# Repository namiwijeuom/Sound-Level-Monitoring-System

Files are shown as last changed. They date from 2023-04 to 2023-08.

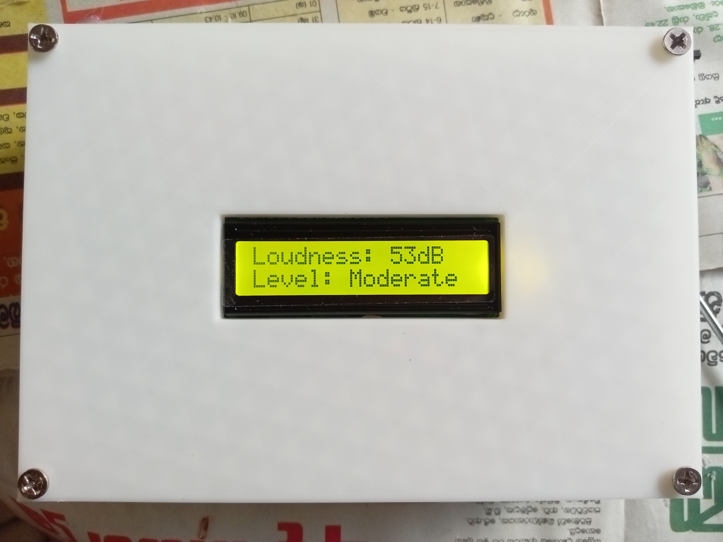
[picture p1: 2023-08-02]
Mid Evaluation Files/IMG_20230611_141432_171.jpg

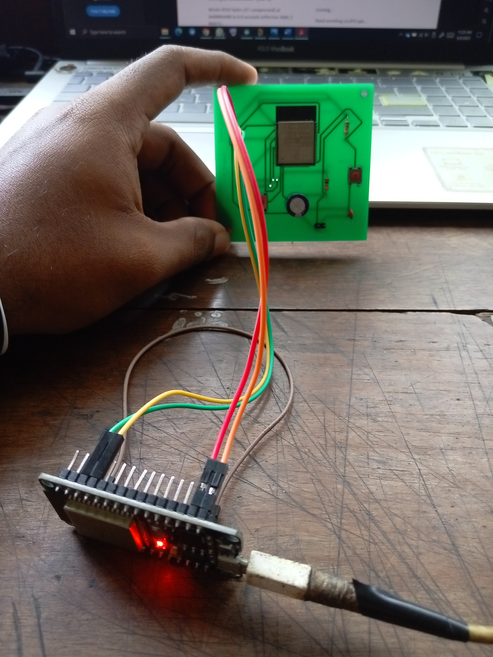
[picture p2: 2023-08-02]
Mid Evaluation Files/IMG_20230603_112545_107.jpg

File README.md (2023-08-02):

# Sound-Level-Monitoring-System
This is an individual project conducted under the module EN2160 - Engineering Design Realization, Semester 4, Department of Electronic and Telecommunication Engineering, University of Moratuwa, Sri Lanka.

Simulation Results- https://wokwi.com/projects/362552575811746817

Inside The First Prototype

It was not easy as before because all the designing and configuring tasks were to be done indicidually.

Before the Final Product

But it was an amazing experience to get on hands on experience on electronic product design and learned so many things at the end.

Final Product

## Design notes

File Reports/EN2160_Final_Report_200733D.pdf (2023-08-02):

1 | P a g e

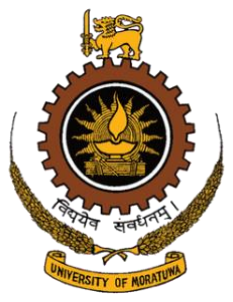
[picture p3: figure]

Department of Electronic and Telecommunication Engineering

University of M oratuwa

Final Report - Sound Level M onitoring System

Wijetunga W.L.N.K | - | 200733D

This report is submitted as a partial fulfillment of the module

EN2160 – Electronic Design Realization

24

th of July 2023

2 | P a g e

## Content

1. Introduction
2. Product Identification
3. Specifications of the Product
4. Extra Features That Are Included
5. Simulation
6. Conceptual Design
a. Conceptual designs for the product
i. Design - 1
ii. Design - 2
iii. Design - 3
b. Block diagrams drawn for the product
i. Block Diagram - 1
ii. Block Diagram - 2
iii. Block Diagram - 3
7. User Centred Design
a. Sketch
b. Block diagram
8. Evaluation Matrices
a. For the conceptual designs
b. Features added and removed in each design
c. For the block diagrams
d. Features added and removed in each block diagram
9. Selected Designs of the Product
a. Conceptual design
b. Block diagram
10. Implemented Designs of the Product
a. Schematic of the Implemented Design
b. Enclosure Design of the Implemented Design
c. PCB Design
11. First Prototype
12. Problems and Improvements of the Implemented Design
a. Problems/Improvements identified/proposed during the mid-evaluation

3 | P a g e
b. Problems/Improvements identified/proposed by users.
13. Improved Design
a. Schematic of the Improved Design
b. Enclosure Design of the Improved Design
c. PCB design and Gerber Files
14. The Product After Improvements
15. Any instructions for assembly
16. How to test for functionality
17. Bill of Materials
18. Appendix
19. References

4 | P a g e
1. Introduction
- Among the major types of pollution happening in the world such as water pollution and air pollution, sound pollution is getting a special attention in the society.
- Sound pollution is becoming a major concern in urban areas where there are high traffic conditions, in factories where there are large machines that generate noise and in work sites which involves using explosives a lot.
- With these promising issues, people tend to check the sound pollution level in their living area on a periodical manner and they tend to keep a track on past the sound pollution levels in the area currently.
2. Product Identification
- There are products already available in the market that can detect the sound level in a specific place.
- Examples of such devices can be found using the following links.
- https://www.amazon.com/noise-detector/s?k=noise+detector
- https://www.aliexpress.com/w/wholesale-automotive-noise-detector.html
- https://www.renkeer.com/noise-detectors-for-industrial-pollution/ ‘
- But they cannot keep a record either on the location or the past data.
- Considering the above-mentioned factors, it was decided to build a sound level monitoring device that can monitor and display the sound quality and level in a specific location and the data is directly stored in a database for further analysis.
- The device will be an IoT device as well.
- The level of sound will be displayed on a screen so the user can see the amount of sound pollution in decibels.
- It will further indicate whether the sound pollution level is low, intermediate, or high.
- It will be a portable device which can carried easily so the user does not need any extra space to pack the device.
3. Specifications of the Product
- The primary and foremost objective of this device revolves around its paramount capability to measure the prevailing sound level accurately and precisely within a designated area. Subsequently, this crucial acoustic data is meticulously stored in an extensive and comprehensive database, paving the way for exhaustive and in-depth analysis in the subsequent stages.
- Utilizing cutting-edge technology, the device employs a sound sensor to diligently gauge the acoustic intensity, precisely quantifying it in decibels (dB). This valuable information is then seamlessly portrayed on a highly convenient LCD display, thereby facilitating a comprehensive understanding of the prevailing sound pollution level in the environment.
- Users of this ingeniously designed device are presented with the invaluable privilege of effortlessly perceiving the sound level through the highly user-friendly display. Furthermore, they are granted unhindered access to an easily accessible ON/OFF switch, thereby empowering them with absolute control overpowering the device as they see fit.

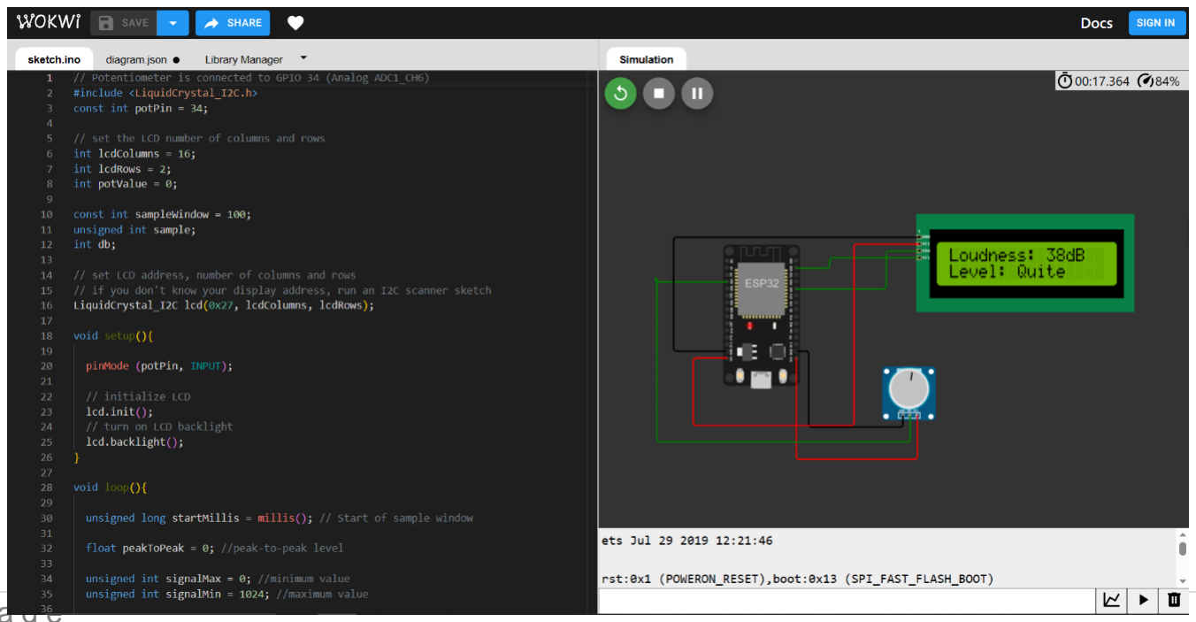
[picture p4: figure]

5 | P a g e
- To ensure optimal functionality, the device warrants a steadfast 5V power supply to effectively power up its intricate modules. Nevertheless, users are afforded the liberty to swap out drained batteries with utmost ease, thus ensuring a continuous and seamless operation of the device without any interruptions.
4. Extra Features That Are Included
- Along with the sound pollution level in dB being displayed in the LCD display, it will also be pushing the readings to an IoT platform, and a graph will be plotted over time to see the sound level in that specific location.
- It will indicate whether the sound level in the area is quiet, medium, high, or high risk in the display.
- As the IoT platform, Blynk IoT platform will be used, and it is accessible to anyone around the world.
5. Simulation
- Before implementing the solution, the functionality of the circuit proposed for the product was simulated and verified.
- The platform used was Wokwi online simulator.
- Wokwi Arduino simulator is a great online tool for simulating projects that use a development board. The app supports various popular development boards and MCUs such as the Arduino UNO, the Raspberry Pi Pico, the ESP32, and the ATTiny85.
- Therefore, during the simulation instead of using the ESP32-WROOM32D microcontroller, ESP32 Development board was used because the microcontroller alone was not available in the simulation platform.
- During the simulation, the microphone module that was proposed to be used for the product was not available.
- A microphone module captures sound in the environment and outputs a voltage signal which is proportional to the sound level.
- Therefore, the functionality of the microphone module was simulated using a potentiometer.
- The Wi-Fi connection and the things associated with Blynk application was not simulated and they were tested during the breadboard implementation of the proposed circuit.

Figure 1

6 | P a g e
- Link for the simulation - EDR_Sound_Level_Detection_System_V2 - Wokwi ESP32, STM32, Arduino Simulator (https://wokwi.com/projects/362552575811746817)
- Sketch used during the simulation is as follows.

// Potentiometer is connected to GPIO 34 (Analog ADC1_CH6) #include <LiquidCrystal_I2C.h>
const int potPin = 34;

// set the LCD number of columns and rows int lcdColumns = 16;
int lcdRows = 2;
int potValue = 0;

const int sampleWindow = 100; unsigned int sample;
int db;

// set LCD address, number of columns and rows
// if you don't know your display address, run an I2C scanner sketch LiquidCrystal_I2C lcd(0x27, lcdColumns, lcdRows);

void setup(){

pinMode (potPin, INPUT);

// initialize LCD
lcd.init();
// turn on LCD backlight
lcd.backlight();
}

void loop(){

unsigned long startMillis = millis(); // Start of sample window

float peakToPeak = 0; //peak-to-peak level

unsigned int signalMax = 0; //minimum value unsigned int signalMin = 1024; //maximum value

// collect data for 50 mS
while (millis() - startMillis < sampleWindow)
{

sample = analogRead(potPin); //get reading from microphone

if (sample < 1024) // toss out spurious readings
{
if (sample > signalMax)
{

7 | P a g e

signalMax = sample; // save just the max levels }
else if (sample < signalMin)
{
signalMin = sample; // save just the min levels }
}
}

peakToPeak = signalMax - signalMin; // max - min = peak-peak amplitude

Serial.println(peakToPeak);

db = map(peakToPeak, 50, 4000, 49.5, 90); //calibrate for deciBels

lcd.setCursor(0, 0);
lcd.print("Loudness: ");
lcd.print(db);
lcd.print("dB");

if (db <= 40)
{
lcd.setCursor(0, 1);
lcd.print("Level: Quite"); }
else if (db > 40 && db < 55)
{
lcd.setCursor(0, 1);
lcd.print("Level: Moderate"); }
else if (db >= 55)
{
lcd.setCursor(0, 1);
lcd.print("Level: High");
}
delay(600);
lcd.clear();
}

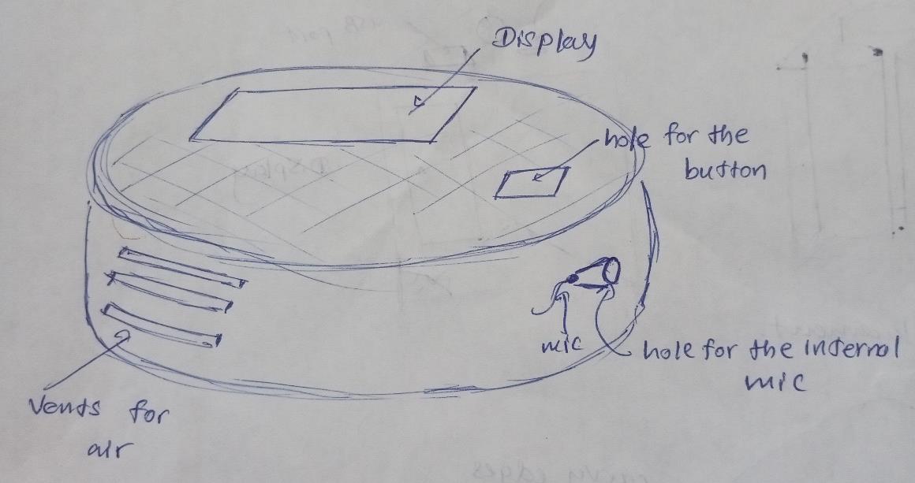
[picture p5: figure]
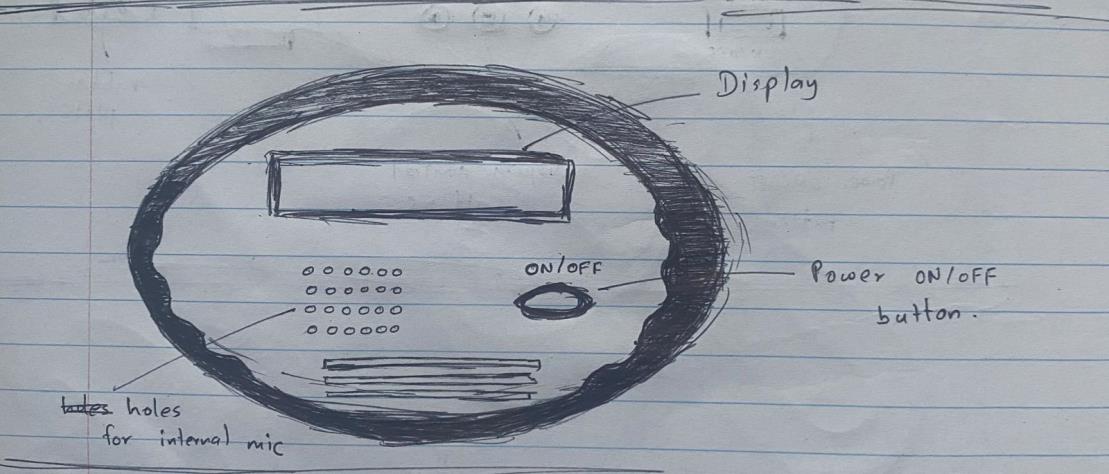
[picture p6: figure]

8 | P a g e
6. Conceptual Designs of the Product
- In the conceptual design cycle of designing concepts and making prototypes, different circuits, enclosures, and functional parts (If available) are considered by brainstorming ideas among the members of the design team.
- Then those ideas are combined to make a complete solution to the problem which is addressed.
- The underlying ideas are then grouped and using hand sketches those ideas are presented to get the optimal solution.
- Conceptual Designs Drawn
- After having many brainstorming sessions, the following conceptual designs were developed for the sound level monitoring system.
a) Design - 1 (Inspired from Amazon ALEXA)
b) Design - 2 (Handheld type design)

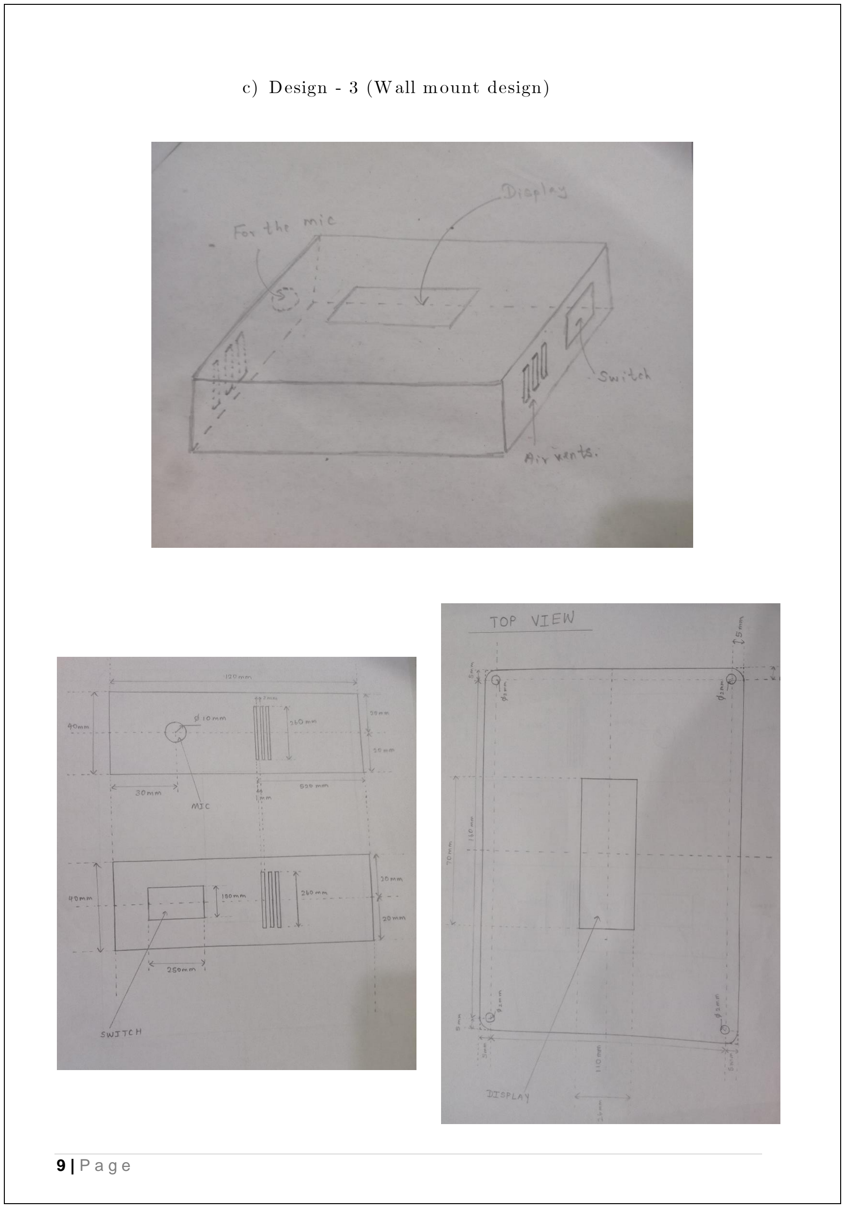
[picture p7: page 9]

9 | P a g e
c) Design - 3 (Wall mount design)

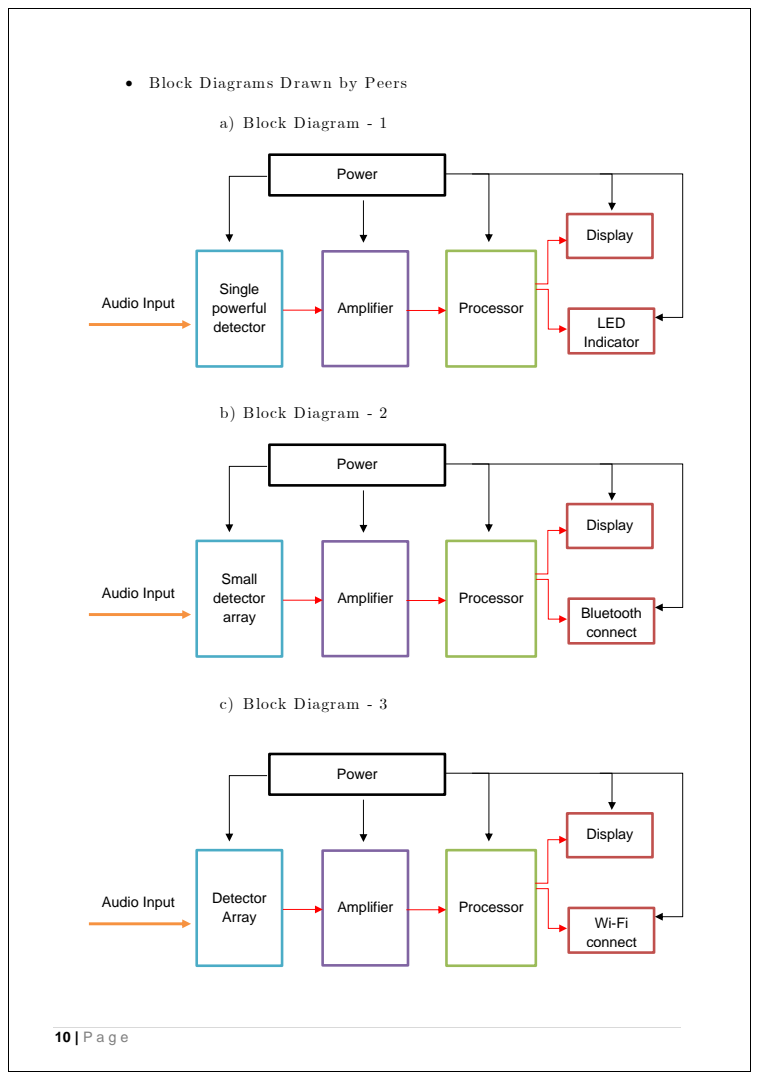
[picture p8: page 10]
a) Block Diagram - 1; b) Block Diagram - 2; c) Block Diagram - 3; Single powerful detector; Amplifier; Processor; Display; LED Indicator; Power; Audio Input; Small detector array; Bluetooth connect; Detector; Array; Wi-Fi connect

• Block Diagrams Drawn by Peers

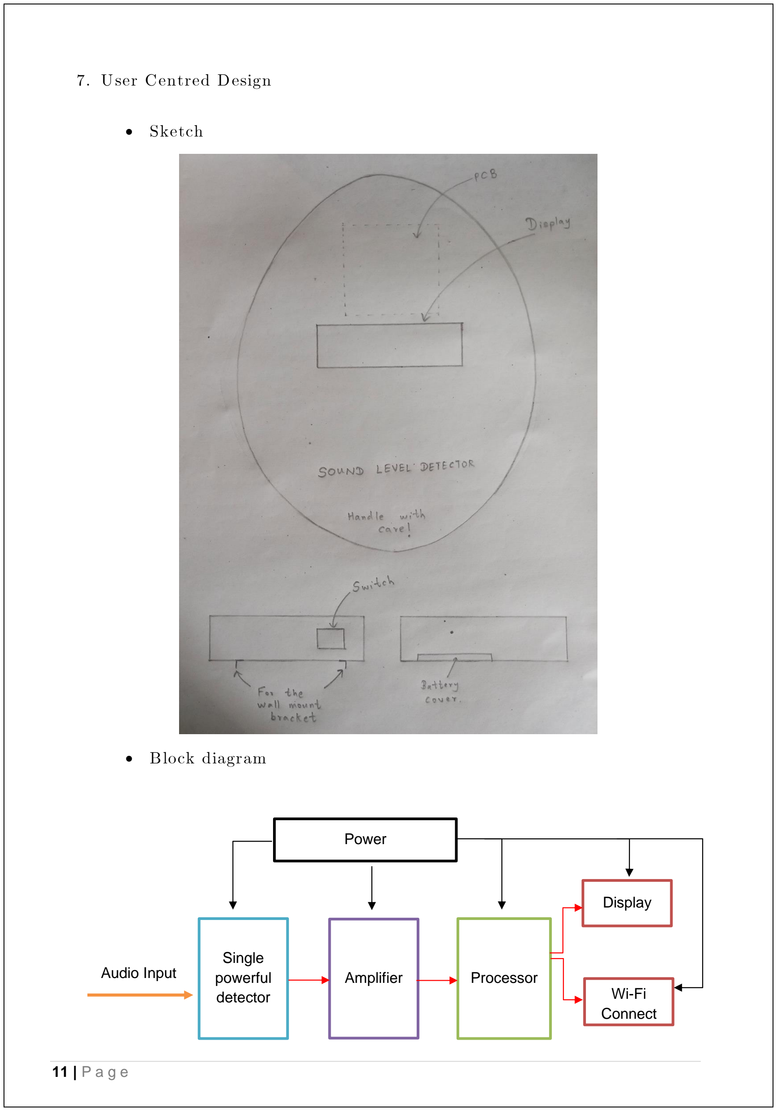
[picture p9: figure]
7. User Centred Design; • Sketch; • Block diagram; Single powerful detector; Amplifier; Processor; Display; Wi-Fi Connect; Power; Audio Input

12 | P a g e
8. Evaluation M atrices
- For the conceptual designs
- Features added and removed in each design
No. | Criterion | Design - 1 (Inspired from Amazon ALEXA) | Design - 2 (Handheld Type Design) | Design - 3 (Wall Mount Type Design) | Design - 4 (User Centred Design)
1 | Portability | 0 | 10 | 0 | 0
2 | Simplicity | 9 | 4 | 8 | 7
3 | Repairability | 8 | 8 | 8 | 8
4 | Manufacturability | 7 | 7 | 7 | 7
5 | Indoor use | 10 | 8 | 10 | 10
6 | Outdoor use | 0 | 4 | 9 | 0
7 | User friendliness | 5 | 3 | 8 | 6
8 | Aesthetic view | 5 | 4 | 3 | 5
9 | Competitiveness with existing products | 6 | 3 | 8 | 8
10 | Eco friendliness | 6 | 6 | 6 | 6
| Total M arks | 56 | 57 | 69 | 57
Criterion | Design - 1 (Inspired from Amazon ALEXA) | Design - 2 (Handheld Type Design) | Design - 3 (Wall Mount Type Design) | Design - 4 (User Centred Design)
Added features | • Indoor use • Simplicity | • Portability • Indoor use | • Both indoor and outdoor use | • Indoor use • Competitiveness with existing products
Removed features | • Outdoor use | • Simplicity | • Portability | • Portability • Outdoor use

13 | P a g e
- For the block diagrams
- Features added and removed in each block diagram
No. | Criterion | Block Diagram - 1 | Block Diagram - 2 | Block Diagram - 3 | Block Diagram - 4 (User Centred Design)
1 | Battery life | 8 | 6 | 6 | 6
2 | Simplicity | 6 | 6 | 5 | 5
3 | Repairability | 5 | 5 | 5 | 5
4 | Manufacturability | 6 | 6 | 6 | 6
5 | Indoor/Outdoor use | 5 | 3 | 5 | 5
6 | User friendliness | 4 | 7 | 8 | 6
7 | Response time | 6 | 7 | 7 | 7
8 | Reliability | 4 | 6 | 8 | 8
9 | Accuracy | 5 | 6 | 6 | 5
10 | Range | 4 | 8 | 7 | 6
| Total M arks | 53 | 60 | 63 | 59
Criterion | Block Diagram - 1 | Block Diagram - 2 | Block Diagram - 3 | Block Diagram - 4 (User Centred Design)
Added features | • Only one powerful detector to detect sound | • A detection array instead of a single detector for sound detection | • A detection array instead of a single detector for sound detection | • A detection array instead of a single detector for sound detection
Removed features | • No Wi-Fi or Bluetooth connection can be enabled. | • No Wi-Fi connection can be enabled. | • No Bluetooth connection can be enabled. | • No Bluetooth connection can be enabled.

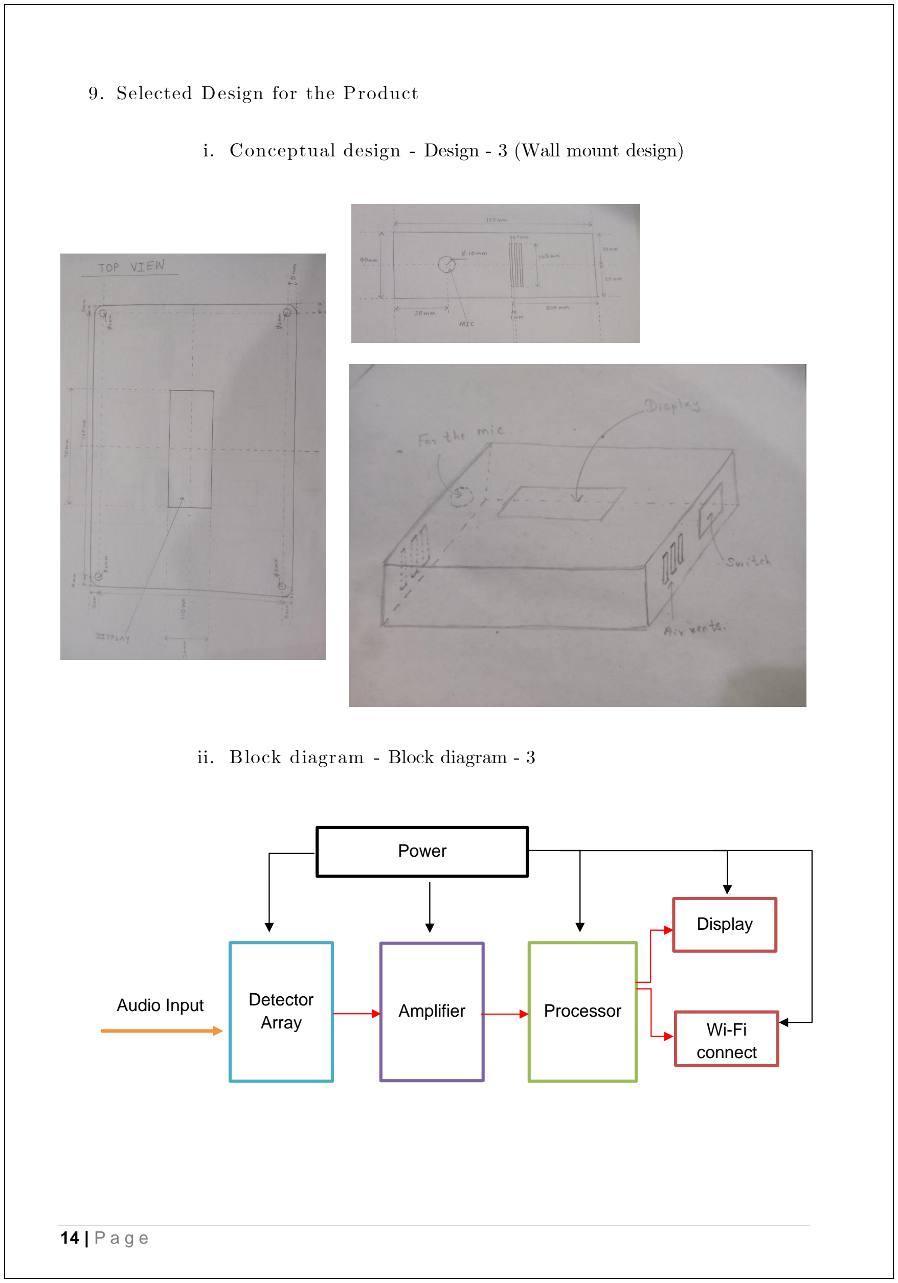
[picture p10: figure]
9. Selected Design for the Product; ii. Block diagram - Block diagram - 3; Detector; Array; Amplifier; Processor; Display; Wi-Fi connect; Power; Audio Input

i. Conceptual design - Design - 3 (Wall mount design)

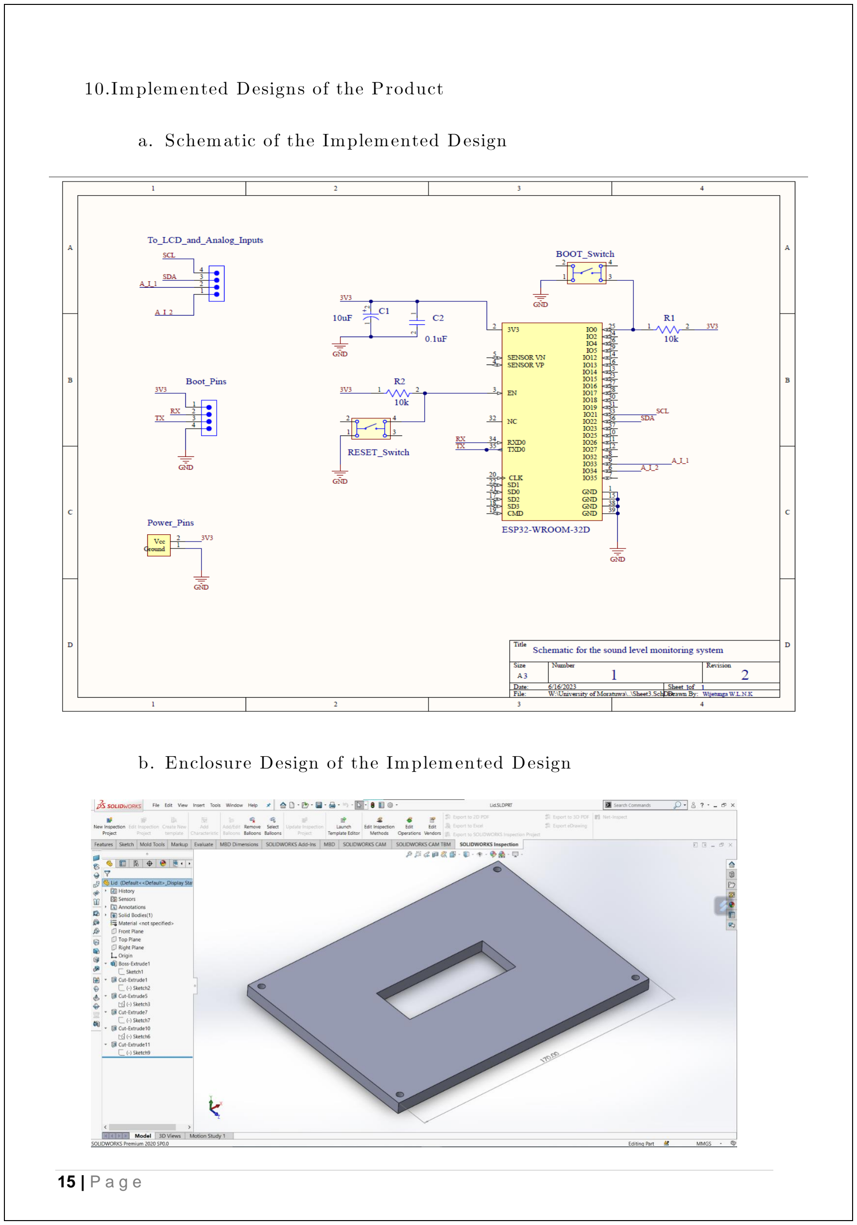
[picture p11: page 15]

15 | P a g e

10.Implemented Designs of the Product

a. Schematic of the Implemented Design
b. Enclosure Design of the Implemented Design

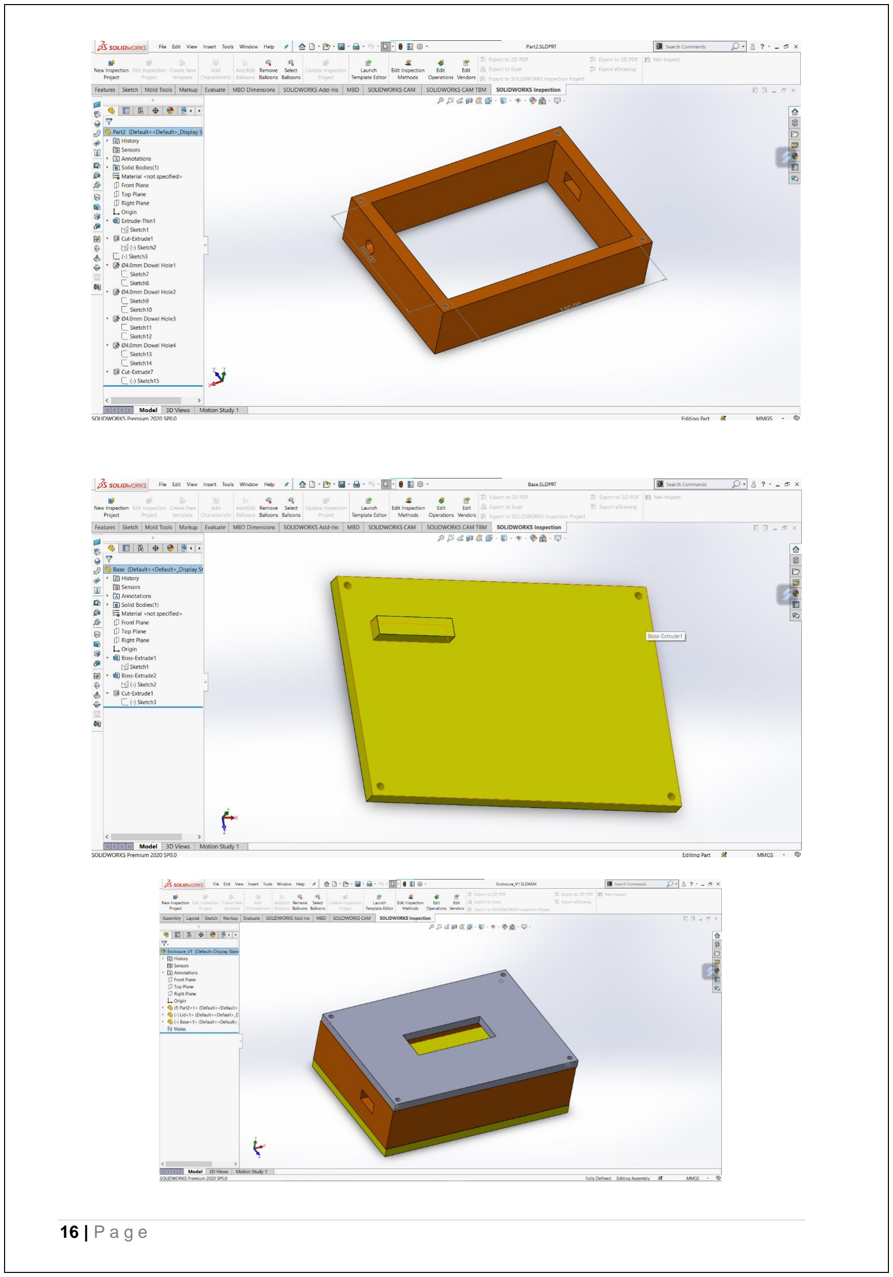
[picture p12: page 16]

16 | P a g e

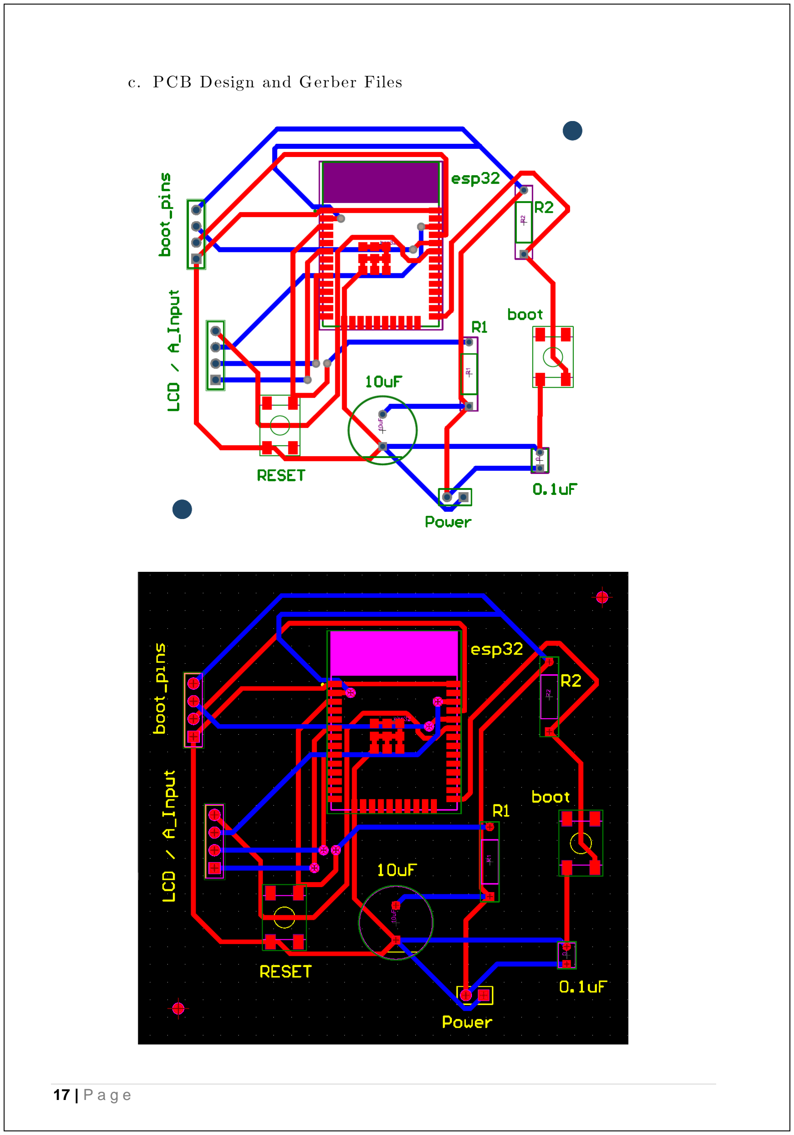
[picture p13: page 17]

17 | P a g e
c. PCB Design and Gerber Files

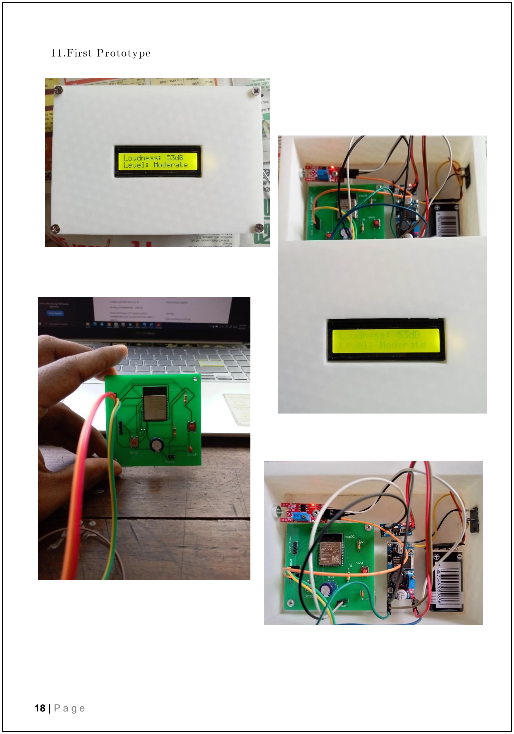
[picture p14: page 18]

18 | P a g e

11.First Prototype

19 | P a g e

12.Problems and Improvements of the Implemented Design

a. Problems/Improvements identified/proposed during the mid-evaluation
i. The initial rendition of the product's enclosure design featured a rather simplistic and utilitarian box-shaped configuration.
ii. Following the invaluable feedback received during the mid-evaluation stage, it became evident that the design lacked visual appeal, with its unattractive aesthetics failing to impress.
iii. Subsequently, in response to the constructive critique, the enclosure design underwent a complete overhaul, incorporating elegant curves and fillets to infuse it with a more captivating and alluring appearance.
iv. A thorough examination of the PCB revealed the possibility of optimizing its layout by strategically integrating the power supply modules within the board itself. The rationale behind this suggestion was twofold: not only would it free up precious space inside the enclosure, but it would also lead to a reduction in the number of interconnecting wires, streamlining the overall design and enhancing its efficiency.
b. Problems/Improvements identified/proposed by users.
i. In response to the valuable feedback received during the mid-evaluation, proactive measures were taken to revamp the product's appearance. To explore various visually striking options, a series of conceptual designs were meticulously sketched, aiming to identify an alluring and captivating look for the device.
ii. | The idea of adding Bluetooth connection to the device in addition to the
| Wi-Fi connectivity was suggested by one pf the group members. The
| justification for this was sometimes it is easy to use and implement
| Bluetooth connectivity rather than using Wi-Fi specially in a smaller
| physical area.
iii. | The users' delight knew no bounds upon learning that the device had
| evolved into a full-fledged Internet of Things (IoT) device, significantly
| expanding its functionality and potential use cases.
iv. | The overwhelming consensus among users was the pressing need to
| integrate Bluetooth connectivity into the device, echoing the sentiment put
| forth by their colleagues, thereby solidifying its status as a versatile and
| user-friendly product.
v. As a result of constructive criticism from users, there was a strong
| recommendation to diligently enhance and refine the product's design,
| which was deemed unappealing. This feedback served as a driving force
| behind the pursuit of a visually captivating and aesthetically pleasing
| appearance for the device.

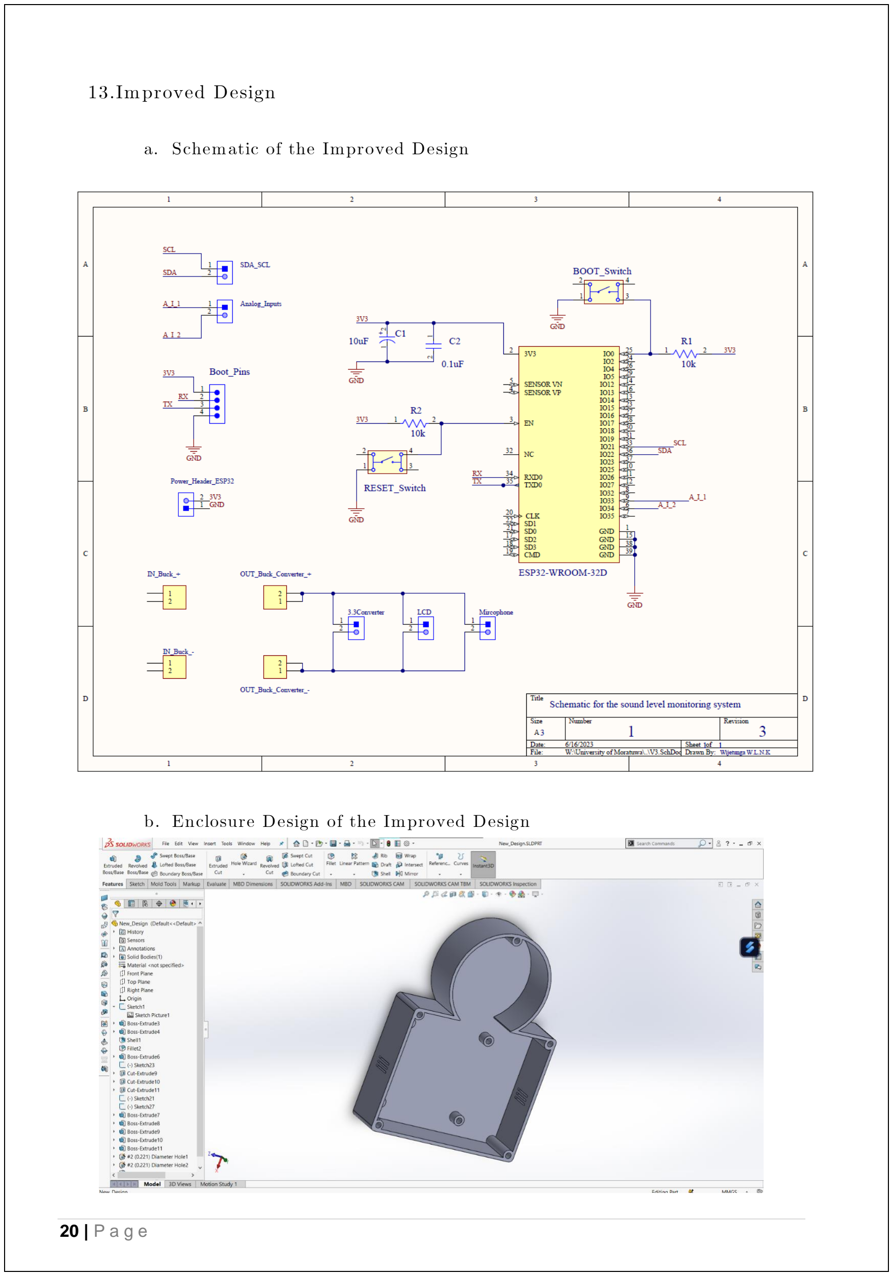
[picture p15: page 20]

20 | P a g e

13.Improved Design

a. Schematic of the Improved Design
b. Enclosure Design of the Improved Design

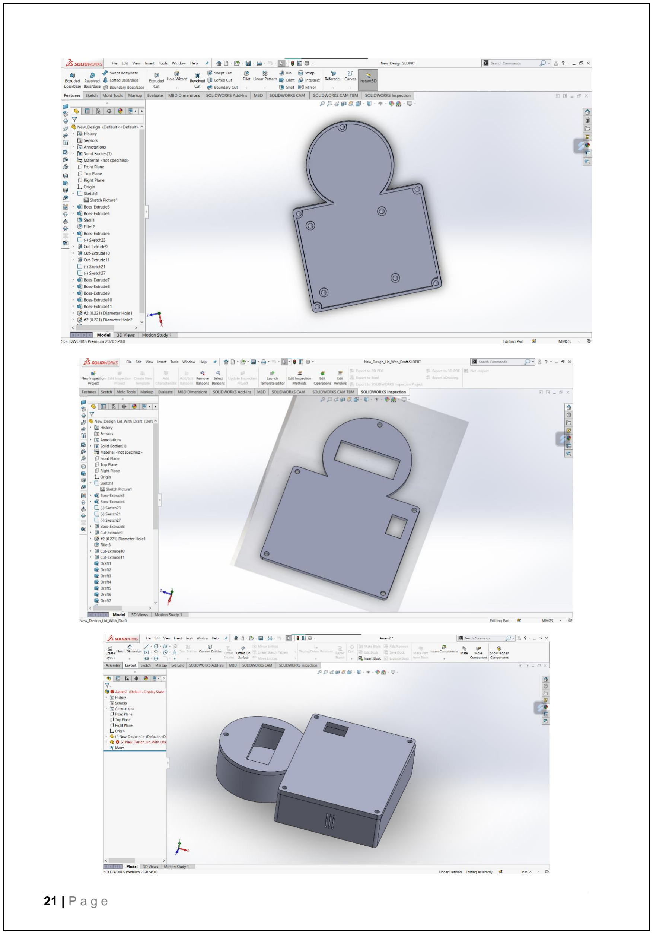
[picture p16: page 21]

21 | P a g e

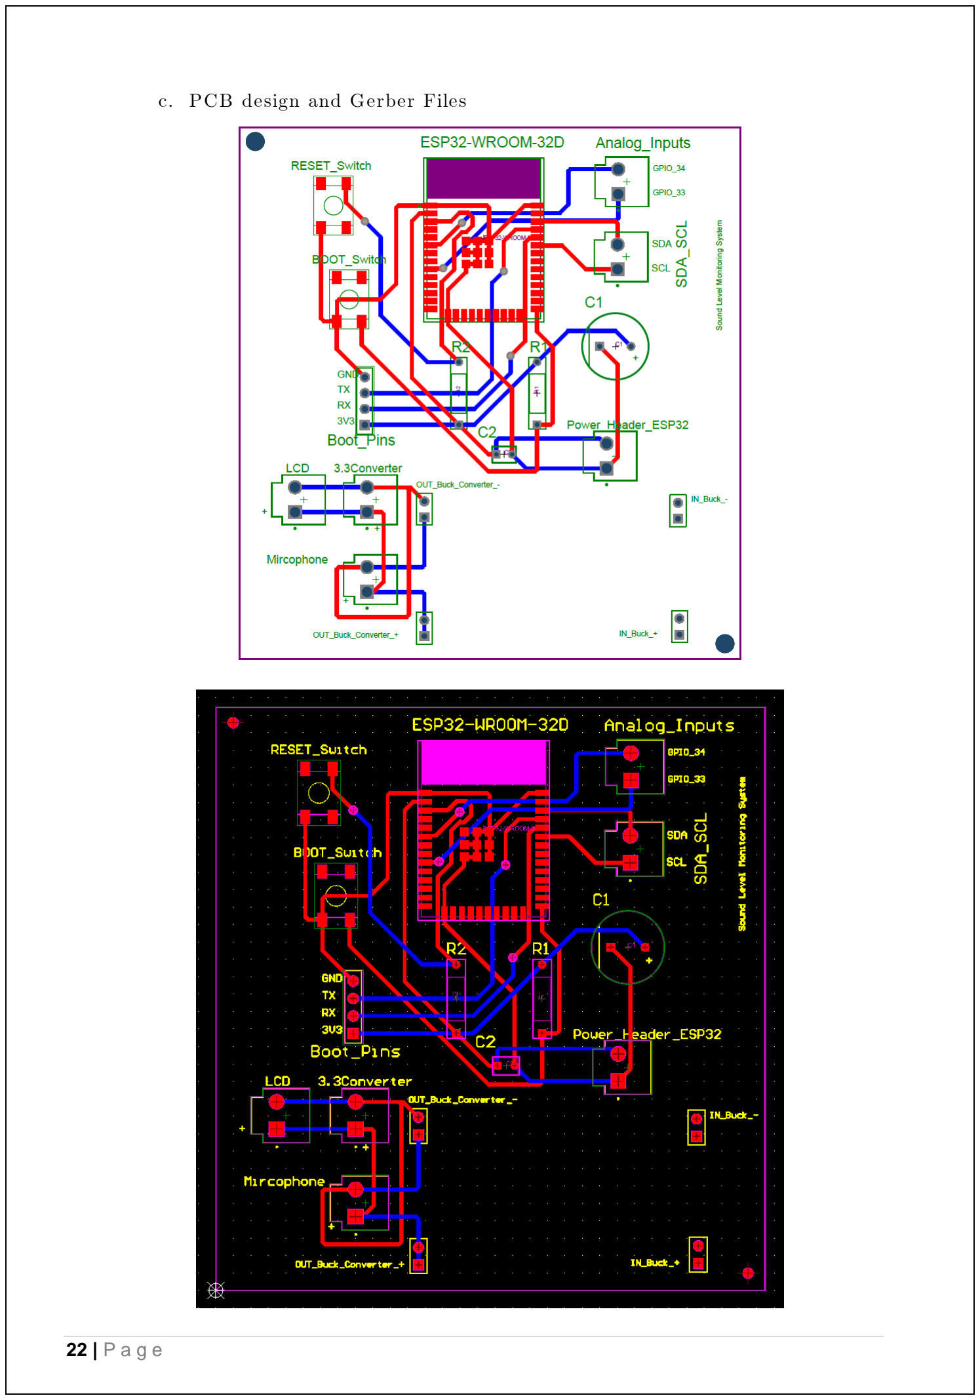
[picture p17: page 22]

22 | P a g e
c. PCB design and Gerber Files

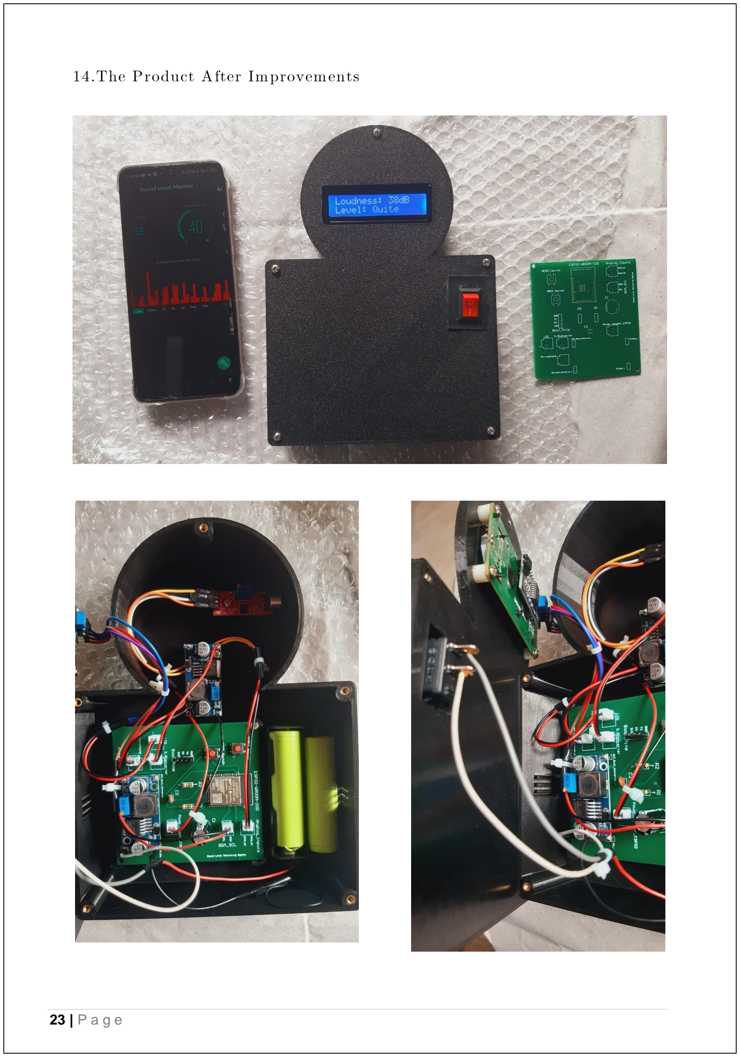
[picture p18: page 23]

23 | P a g e

14.The Product After Improvements

24 | P a g e
- The sketch used for the ESP32 is as follows.

/* Fill-in information from Blynk Device Info here */ #define BLYNK_TEMPLATE_ID "TMPL6R8cIYZ6A"
#define BLYNK_TEMPLATE_NAME "Quickstart Template"

#define BLYNK_AUTH_TOKEN "DKvORhrPqRP_jFrWe91_ADIEHiUbJ54X"

/* Comment this out to disable prints and save space */ #define BLYNK_PRINT Serial

// Potentiometer is connected to GPIO 34 (Analog ADC1_CH6) #include <WiFi.h>
#include <WiFiClient.h>

#include <BlynkSimpleEsp32.h>

#include <LiquidCrystal_I2C.h>

//Wifi connection
const char* ssid = "Namina_Wijetunga"; const char* password = "Iamthebest1ever@"; int WiFiStatus;
String Get_WiFiStatus(int Status){ switch(Status){
case WL_IDLE_STATUS:
return "WL_IDLE_STATUS";
case WL_SCAN_COMPLETED:
return "WL_SCAN_COMPLETED"; case WL_NO_SSID_AVAIL:
return "WL_NO_SSID_AVAIL"; case WL_CONNECT_FAILED:
return "WL_CONNECT_FAILED"; case WL_CONNECTION_LOST:
return "WL_CONNECTION_LOST"; case WL_CONNECTED:
return "WL_CONNECTED";
case WL_DISCONNECTED:
return "WL_DISCONNECTED";
}
}

const int potPin = 34;

// set the LCD number of columns and rows int lcdColumns = 16;
int lcdRows = 2;
int potValue = 0;

const int sampleWindow = 50; unsigned int sample;
int db;

// set LCD address, number of columns and rows

25 | P a g e

// if you don't know your display address, run an I2C scanner sketch LiquidCrystal_I2C lcd(0x27, lcdColumns, lcdRows);

BlynkTimer timer;

// This function is called every time the Virtual Pin 5 state changes BLYNK_WRITE(V5)
{
int pinValue = param.asInt();
Blynk.virtualWrite(V5, pinValue);
}

// This function is called every time the device is connected to the Blynk.Cloud BLYNK_CONNECTED()
{
// Change Web Link Button message to "Congratulations!"
Blynk.setProperty(V3, "offImageUrl", "https://static-image.nyc3.cdn.digitaloceanspaces.com/general/fte/congratulations.png"); Blynk.setProperty(V3, "onImageUrl", "https://static-image.nyc3.cdn.digitaloceanspaces.com/general/fte/congratulations_pressed.png"); Blynk.setProperty(V3, "url", "https://docs.blynk.io/en/getting-started/what-do-i-need-to-blynk/how-quickstart-device-was-made");
}

// This function sends device's uptime every second to Virtual Pin 2. void myTimerEvent()
{
// You can send any value at any time.
// Please don't send more that 10 values per second. Blynk.virtualWrite(V2, millis() / 1000); Blynk.virtualWrite(V5, db);
}

void setup(){

pinMode (potPin, INPUT);
// initialize LCD
lcd.init();
// turn on LCD backlight
lcd.backlight();

//Serial.begin(115200);
lcd.setCursor(0, 0);
lcd.println("Welcome");
lcd.clear();

WiFi.begin(ssid, password); WiFiStatus = WiFi.status(); while(WiFiStatus != WL_CONNECTED){ delay(250);
WiFiStatus = WiFi.status();

26 | P a g e

//lcd.println(Get_WiFiStatus(WiFiStatus)); //lcd.clear();
}
//lcd.clear();
//lcd.setCursor(0, 0);
//lcd.print("WiFi Enabled"); //lcd.clear();

lcd.setCursor(0, 0);
lcd.print("Welcome");
lcd.setCursor(0, 1);
lcd.print(WiFi.localIP()); delay(500);

lcd.clear();
//Conneting to the Blynk IoT Server
Blynk.begin(BLYNK_AUTH_TOKEN, ssid, password);
// You can also specify server:
//Blynk.begin(BLYNK_AUTH_TOKEN, ssid, password, "blynk.cloud", 80); //Blynk.begin(BLYNK_AUTH_TOKEN, ssid, password, IPAddress(192,168,1,100), 8080);

// Setup a function to be called every second
timer.setInterval(1000L, myTimerEvent);
}

void loop(){

Blynk.run();
timer.run();

unsigned long startMillis = millis(); // Start of sample window

float peakToPeak = 0; //peak-to-peak level

unsigned int signalMax = 0; //minimum value unsigned int signalMin = 1024; //maximum value

// collect data for 50 mS
while (millis() - startMillis < sampleWindow)
{

sample = analogRead(potPin); //get reading from microphone

if (sample < 1024) // toss out spurious readings
{
if (sample > signalMax)
{
signalMax = sample; // save just the max levels }
else if (sample < signalMin)
{

27 | P a g e

signalMin = sample; // save just the min levels }
}
}

peakToPeak = signalMax - signalMin; // max - min = peak-peak amplitude

//Serial.println(peakToPeak);

db = map(peakToPeak, 20, 400, 30, 75); //calibrate for deciBels

lcd.setCursor(0, 0);
lcd.print("Loudness: ");
lcd.print(db);
lcd.print("dB");

if (db <= 40)
{
lcd.setCursor(0, 1);
lcd.print("Level: Quite"); }
else if (db > 40 && db < 60)
{
lcd.setCursor(0, 1);
lcd.print("Level: Moderate"); }
else if (db >= 60)
{
lcd.setCursor(0, 1);
lcd.print("Level: High");
}
delay(600);
lcd.clear();
}
- Here, as the IoT platform, Blynk is used and by downloading the Blynk IoT app from Android Play store of Apple Appstore, it can be configured to receive data from the device.
- In the app, the device uptime, real time sound level and the sound level variation over time is shown.

28 | P a g e

15.Any Instructions for Assembly

- It is recommended to use the following sensor models for accurate measurement of sound and displaying its level.
i. Microphone module - Voice Sound Detection Mic Sensor Module
ii. Buck converter - LM2596S 3-40V to 1.5-35V 4A DC to DC Adjustable Step-Down Buck Module
- When removing the lid for battery replacement, careful with the wires which are connected to the LCD display. They may get disconnected if handled carelessly.

16.How to Test for Functionality

- Here are the steps to test for functionality of the sound level monitoring device.
i. Switch on the device. Then the LCD display will be switched on.
ii. Wait for 2-3 seconds and the following items will be displayed on the LCD.

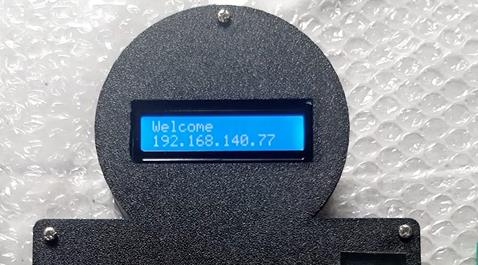
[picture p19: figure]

This means that the device is connected to the Wi-Fi network and its IP address is displayed.

Note: If this is not displayed for more than 10 seconds, switch off the device and again switch on and wait. If that doesn’t work, change the batteries to new ones and switch on the device.

iii. Again wait 2-3 seconds and then the sound level and the intensity will be displayed on the LCD screen as follows.

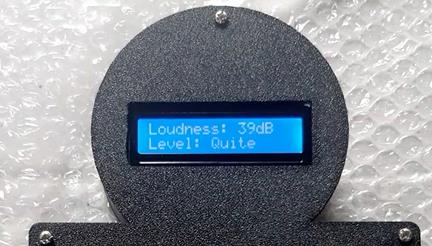
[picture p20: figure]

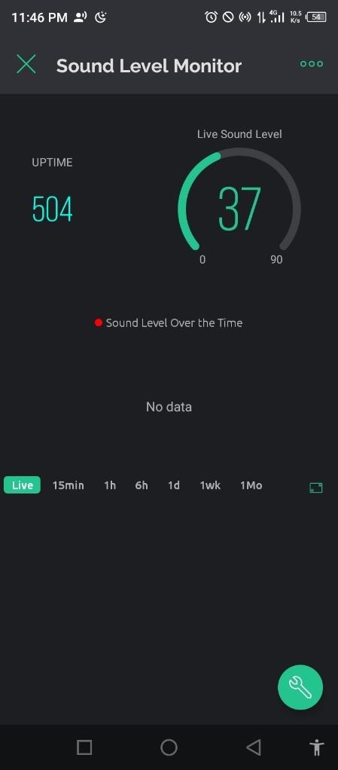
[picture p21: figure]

29 | P a g e

This means that the device is connected to the Blynk server and data is uploaded to the server so it can be accessed through the Blynk app which is installed in the smart phone of the user.

Note: If this is not displayed for more than 10 seconds, switch off the device and repeat step (i).

iv. Open Blynk IoT app in the smart phone and select the sound level monitor to see the real time data coming from the device.

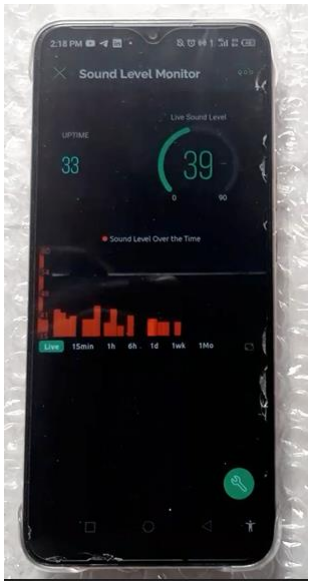
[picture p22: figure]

v. It is recommended to keep the device switched on all times except during the following occasions.
1. When the location of monitoring is going to be changed.
2. When batteries are about to be drained out.
Before Receiving Data | When Receiving Data

30 | P a g e

17.Bill of M aterials

Comment | Description | Designator | Quantity | Supplier
TSW-104-08-L-S | 0.025" SQ Post Header, Through-hole, Vertical, -55 to 125 degC, 2.54 mm Pitch, 4-Pin, Male, RoHS | Boot_Pins | 1 | TronicLK
RCER71H104K0DBH03A | Cap Ceramic 100nF 50V X7R ±10% Radial 2.5mm +125°C Ammo Pack | C2 | 1 | Digikey
MBB02070C1002FCT00 | RES 10K OHM 0.6W 1% AXIAL | R1, R2 | 2 | Digikey
Header 2 | Header, 2-Pin | IN_Buck_-, IN_Buck_+, OUT_Buck_Converter_-, OUT_Buck_Converter_+ | 4 | TronicLK
ESP32-WROOM-32D | WIFI MODULE 32MBITS SPI FLASH | ESP32-WROOM-32D | 1 | Digikey
EEUFC1A102 | Aluminum Electrolytic Capacitors (Radial Lead Type) AEC-Q200 Qualified 1000uF ±20% 10V | C1 | 1 | Digikey
B2P-VH(LF)(SN) | Male Header, Pitch 3.96 mm, 1 x 2 Position, Height 10.9 mm, Tail Length 3.7 mm, -25 to 85 degC, RoHS, Bulk | 3.3Converter, Analog_Inputs, LCD, Mircophone, Power_Header_ESP32, SDA_SCL | 6 | TronicLK
4.30471E+11 | WS-TASV SMD Tact Switch 6X6 mm | BOOT_Switch, RESET_Switch | 2 | Digikey
MD0220 | Voice Sound Detection Mic Sensor Module | | 1 | TronicLK
DM0002 | 1602 16x2 Yellow | | 1 | TronicLK

31 | P a g e
| Backlight LCD Display
MD0042 | LM2596S 3-40V to 1.5-35V 4A DC to DC Adjustable Step-Down Buck Module | 2 | TronicLK

Appendix

GitHub Repository for the project - https://github.com/namiwijeuom/Sound-Level-Monitoring-System.git (https://github.com/namiwijeuom/Sound-Level-Monitoring-System.git)

References

[1] R. Verganti, “Research Summary - Design Driven Innovation,” [Online]. Available: https://www.hbs.edu/faculty/Pages/item.aspx?research=7465. [Accessed 4 6 2023].
[2] Engineering Design Centre, Department of Engineering, University of Cambridge, “Inclusive Design Toolkit,” [Online]. Available: http://www.inclusivedesigntoolkit.com/GS_overview/overview.html. [Accessed 3 6 2023].

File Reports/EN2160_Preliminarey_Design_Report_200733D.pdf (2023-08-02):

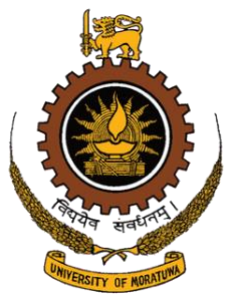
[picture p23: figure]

Department of Electronic and Telecommunication Engineering

University of Moratuwa

Preliminary Design Report

Wijetunga W.L.N.K | - | 200733D

This report is submitted as a partial fulfillment of the module

EN2160 – Electronic Design Realization

16th of June 2023

## Content

1. Introduction
2. Implemented Design
I. Schematic of the Implemented Design
II. SOLIDWORKS Design of the Implemented Design
3. Problems and Improvements
I. Problems identified by you considering the course contend delivered by
| Prof. Jayasinghe.
II. | Problems/Improvements identified/proposed by members of your group.
III. | Problems/Improvements identified/proposed by users.
4. Improved Design
I. Schematic of the Improved Design
II. SOLIDWORKS Design of the Improved Design
5. Side by Side Comparison of the Designs
I. Schematic
II. SOLIDWORKS Design
6. References

### 1. Introduction

- During the preliminary design phase, designers typically create sketches, diagrams, or computer-aided design (CAD) models to visualize and communicate their ideas.
- They consider factors such as performance requirements, user needs, technical feasibility, budget constraints, and safety considerations.
- The goal is to establish a solid foundation for the subsequent detailed design phase by evaluating different design alternatives, identifying potential issues, and refining the overall design concept.

### 2. Implemented Design

- The schematic and the SOLIDWORKS design of the implemented design are as follows.
i. Schematic of the Implemented Design

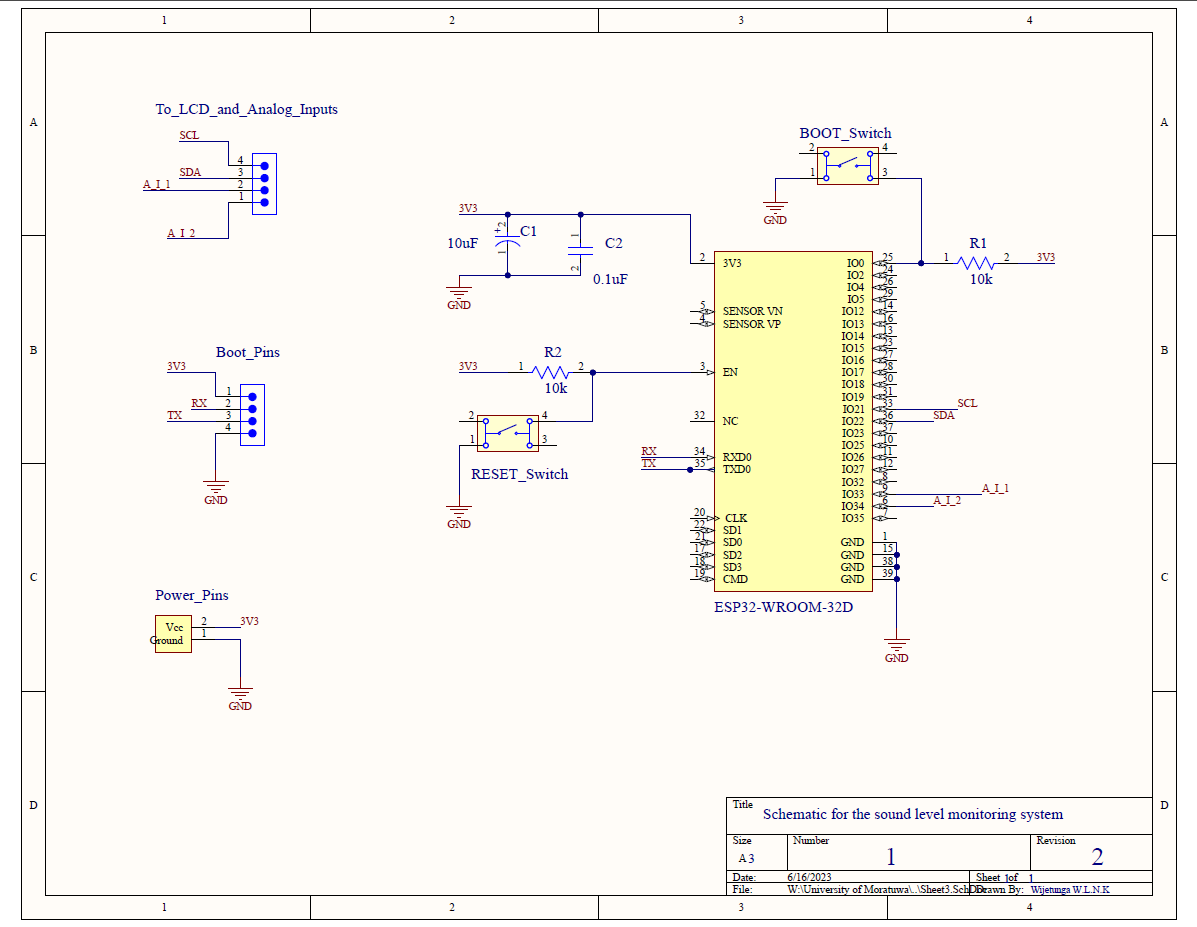
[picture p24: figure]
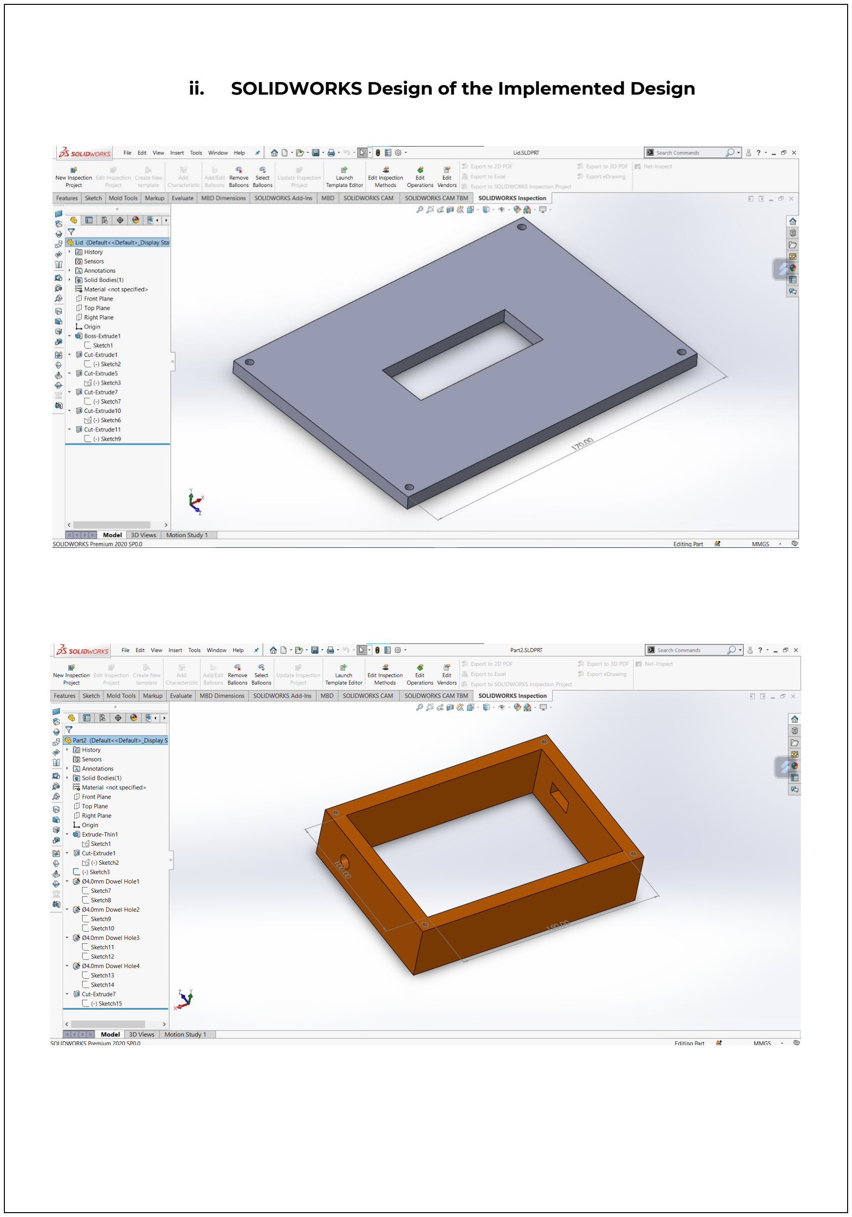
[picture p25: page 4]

ii. SOLIDWORKS Design of the Implemented Design

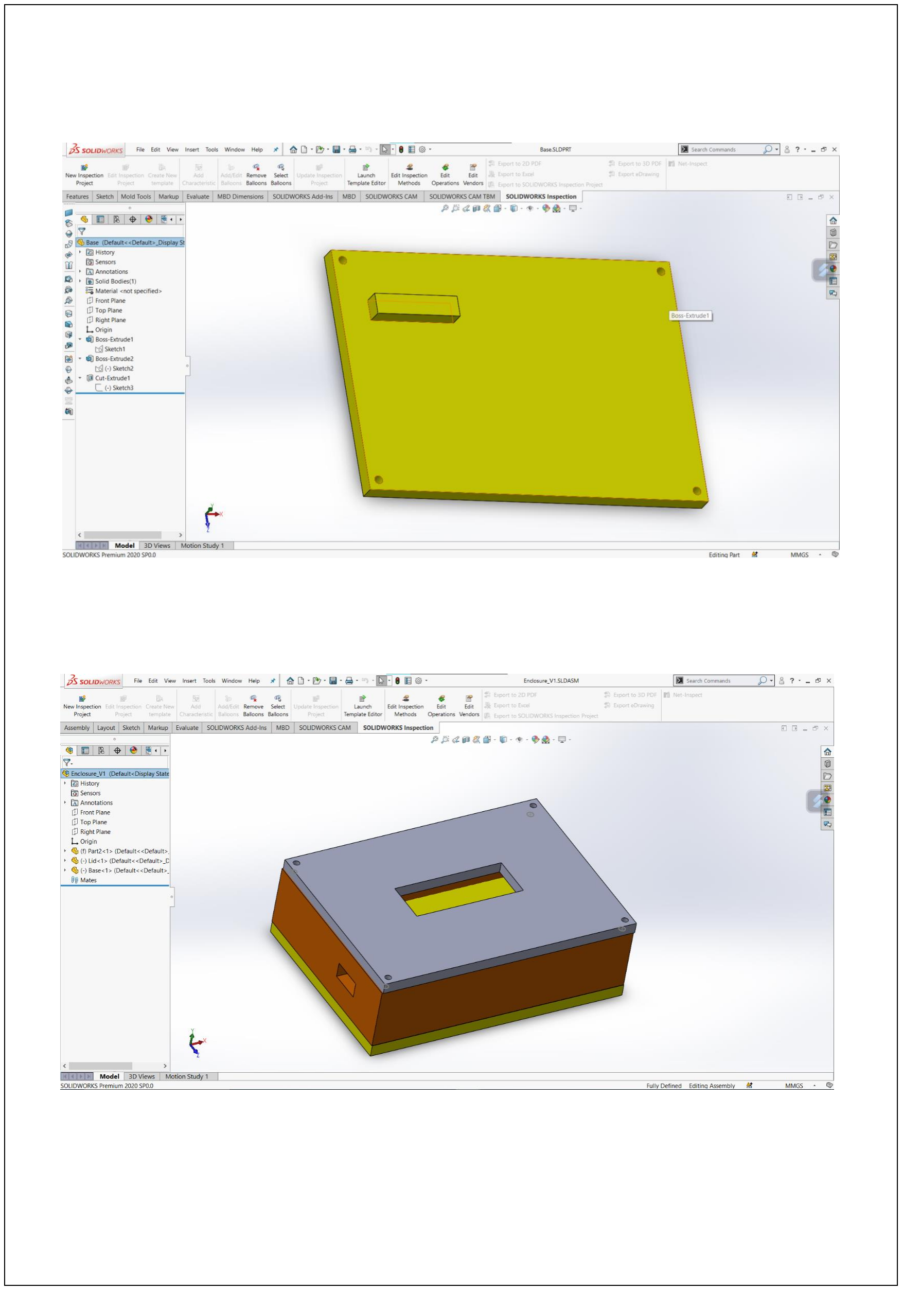
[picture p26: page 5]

### 3. Problems and Improvements


i. Problems identified by you considering the course contend delivered by Prof. Jayasinghe
- The first iteration of the enclosure design of the product had a simple box shaped design.
- Considering the course content covered, it was clear that the design was highly unattractive and does not have an aesthetic view.
- Afterwards it was redesigned by adding curves and fillets to make it more attractive and appealing.
- The first iteration of the product did not have any draft angle, so it was not mouldable.
- With reference to the course content covered, draft analysis was done to all the parts and made everything mouldable.

ii. Problems/Improvements identified/proposed by members of the group.

- From the group members, it was recommended to change the appearance of the product just like in the course content and several sketches were drawn (As conceptual designs) to get an idea on an attractive and appealing appearance for the product.
1st Iteration | 2nd Iteration | Improved Design


- The idea of adding Bluetooth connection to the device in addition to the Wi-Fi connectivity was suggested by one pf the group members. The justification for this was sometimes it is easy to use and implement Bluetooth connectivity rather than using Wi-Fi specially in a smaller physical area.
- Upon analysing the PCB, the group members suggested to design the PCB such that the power supply modules are placed inside the PCB. The justification they gave was that by doing so, the space can be saved inside the enclosure and the number of wires used can be reduced.

iii. Problems/Improvements identified/proposed by users.

- The users were pleased when they heard that the device can be used as an IOT device.
- It was highly recommended by the users to include a way to connect to the device via Bluetooth just like the colleges suggested.
- It was recommended to improve on the design of the product which they found unattractive.

### 4. Improved Design

a. Schematic of the improved design


b. SOLIDWORKS Design of the improved design



### 5. Side by Side Comparison of the Designs

I. Schematic

Implemented

Improved


II. SOLIDWORKS Design

Implemented

Improved

References

[1] Engineering Design Centre, Department of Engineering, University of Cambridge, “Inclusive Design Toolkit,” [Online]. Available: http://www.inclusivedesigntoolkit.com/GS_overview/overview.html. [Accessed 3 6 2023].

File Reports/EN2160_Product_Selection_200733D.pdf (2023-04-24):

# Department of Electronic and Telecommunication Engineering University of Moratuwa EN2160 - Electronic Design Realization Semester 4 Selecting the Product

March 25, 2023

This document is submitted as a partial fulfillment of the module EN2160 Electronic Design Realization

By Wijetunga W.L.N.K (200733D)

1

## Introduction and Problem Identification

- Among the major types of pollution happening in the world such as water pollution and air pollution, sound pollution is becoming a major concern among the society.
- Sound pollution is becoming a major concern in urban areas where there are high traffic conditions, in factories where there are large machines which generate noise and in work sites which involves using explosives a lot.
- With these promising issues, people now tend to check the sound pollution level in their living area on a periodical manner and they tend to keep a track on past the sound pollution levels in the area.
- There are products already available in the market that can detect the sound pollution level in a specific place.
- But they cannot keep a record either on the location or the past data.
- Considering the above mentioned factors, it was decided to build a sound pollution detection device which has the ability to detect and display the sound quality level in on a specific location and the data is directly stored in a database for further analysis.
- The device will be an IoT device as well. The level of sound pollution will be displayed on a screen so the user can see the amount of sound pollution in decibels.
- It will further indicate whether the sound pollution level is low, intermediate or high.
- It will be a portable device which can carried easily so the user doesn’t need any extra spce to pact the device.

## Other Similar Products

Here are some links for the similar products available in the market.

- https://www.amazon.com/noise-detector/s?k=noise+detector
- https://www.aliexpress.com/w/wholesale-automotive-noise-detector.html
- https://www.renkeer.com/noise-detectors-for-industrial-pollution/

The End.

2

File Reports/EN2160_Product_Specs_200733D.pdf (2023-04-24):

# Department of Electronic and Telecommunication Engineering University of Moratuwa EN2160 - Electronic Design Realization Semester 4 The Specifications and Extra Features That are Going to Implement

April 9, 2023

This document is submitted as a partial fulfillment of the module EN2160 Electronic Design Realization

By Wijetunga W.L.N.K (200733D)

1

## The Specifications of the Product

- The primary goal of the device is to measure sound in a particular place and record the value in a graph using Internet of Things (IoT).
- The device will measure the sound in decibels(dB) using a sound sensor and display the level of pollution in a LCD display.
- The user can see the level of sound pollution using the display and will be given access to a ON/OFF switch to turn on and off the power.
- The user has the freedom to reset the device and start again to get the pollution level again and again.
- Since only a 5V power supply should be given to power up the devices and modules, the user will be given the freedom to change the batteries once they are drained.
- The expected dimensions of the final product are as follows.

– Length - 14 cm

– Width - 9 cm

– Height - 5 cm

## Extra Features That is Going to Implement

- Along with the sound pollution level in dB being displayed in the LCD display, it will also be pushing the readings to an IoT platform and a graph will be plotted over time to see the sound pollution level in that specific position.
- It will indicate whether the sound level in the area is quite, medium, high or high risk in the display.
- As the IoT platform, Blynk IoT platform will be used and it is accessible to anyone around the world.
- Even the past data along with location can be accessed for further analysis.

## Major Components Required

- ESP8266 NodeMCU Board
- Microphone sensor
- 16x2 LCD Module

## Useful Data-sheets of the Modules and Micro-controllers

- https://pdf1.alldatasheet.com/datasheet-pdf/view/1148030/ESPRESSIF/ESP8266EX.html
- https://components101.com/modules/lm393-sound-detection-sensor-module
- https://circuitdigest.com/article/16x2-lcd-display-module-pinout-datasheet

The End.

2

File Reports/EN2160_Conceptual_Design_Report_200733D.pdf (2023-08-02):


Department of Electronic and Telecommunication Engineering

University of Moratuwa

Conceptual Designs for the Sound Pollution Monitoring System

Wijetunga W.L.N.K | - | 200733D

This report is submitted as a partial fulfillment of the module

EN2160 – Electronic Design Realization

4

th of June 2023

## Content

1. Introduction
2. Design driven innovation
a. Conceptual designs drawn by peers
i. Design - 1
ii. Design - 2
iii. Design - 3
b. Block diagrams drawn by peers
i. Block Diagram - 1
ii. Block Diagram - 2
iii. Block Diagram - 3
3. User centred design
a. Sketch
b. Block diagram
4. Evaluation matrices
a. For the conceptual designs
b. Features added and removed in each design
c. For the block diagrams
d. Features added and removed in each block diagram
5. Selected Design
a. Conceptual design
b. Block diagram
6. Contribution from group members
7. References

### 1. Introduction

- In the conceptual design cycle of designing concepts and making prototypes, different circuits, enclosures, and functional parts (If available) are considered by brainstorming ideas among the members of the design team.
- Then those ideas are combined to make a complete solution to the problem which is addressed.
- The underlying ideas are then grouped and using hand sketches those ideas are presented to get the optimal solution.

### 2. Design Driven Innovation

- Apart from user centred design technique, there is a second important route to creativity, though: Design-driven innovation which is also known as radical product innovation.
- Instead of being a response to existing user demands, this innovation represents a manufacturer's new vision for what a product could potentially imply for consumers. [1]
- There is an interpreter for the customers who interprets what is new in the product which is not seen in the user centred design.
i. Conceptual Designs Drawn by Peers

After having many brainstorming sessions and discussions among the group members, the following conceptual designs were developed for the sound level monitoring system.

a) Design - 1 (Inspired from Amazon ALEXA)


b) Design - 2 (Handheld type design)
c) Design - 3 (Wall mount design)

Block Diagrams Drawn by Peers; a) Block Diagram - 1; b) Block Diagram - 2; c) Block Diagram - 3; Single powerful detector; Amplifier; Processor; Display; LED Indicator; Power; Audio Input; Small detector array; Bluetooth connect; Detector; Array; Wi-Fi connect

3. User Centred Design; i. Sketch; Block diagram; Single powerful detector; Amplifier; Processor; Display; Wi-Fi Connect; Power; Audio Input

### 4. Evaluation Matrices

a. For the conceptual designs
b. Features added and removed in each design
No. | Criterion | Design - 1 (Inspired from Amazon ALEXA) | Design - 2 (Handheld Type Design) | Design - 3 (Wall Mount Type Design) | Design - 4 (User Centred Design)
1 | Portability | 0 | 10 | 0 | 0
2 | Simplicity | 9 | 4 | 8 | 7
3 | Repairability | 8 | 8 | 8 | 8
4 | Manufacturability | 7 | 7 | 7 | 7
5 | Indoor use | 10 | 8 | 10 | 10
6 | Outdoor use | 0 | 4 | 9 | 0
7 | User friendliness | 5 | 3 | 8 | 6
8 | Aesthetic view | 5 | 4 | 7 | 5
9 | Competitiveness with existing products | 6 | 3 | 8 | 8
10 | Eco friendliness | 6 | 6 | 6 | 6
| Total Marks | 56 | 57 | 71 | 57
Criterion | Design - 1 (Inspired from Amazon ALEXA) | Design - 2 (Handheld Type Design) | Design - 3 (Wall Mount Type Design) | Design - 4 (User Centred Design)
Added features | • Indoor use • Simplicity | • Portability • Indoor use | • Both indoor and outdoor use | • Indoor use • Competitiveness with existing products
Removed features | • Outdoor use | • Simplicity | • Portability | • Portability • Outdoor use

c. For the block diagrams
d. Features added and removed in each block diagram
No. | Criterion | Block Diagram - 1 | Block Diagram - 2 | Block Diagram - 3 | Block Diagram - 4 (User Centred Design)
1 | Battery life | 8 | 6 | 6 | 6
2 | Simplicity | 6 | 6 | 5 | 5
3 | Repairability | 5 | 5 | 5 | 5
4 | Manufacturability | 6 | 6 | 6 | 6
5 | Indoor/Outdoor use | 5 | 3 | 5 | 5
6 | User friendliness | 4 | 7 | 8 | 6
7 | Response time | 6 | 7 | 7 | 7
8 | Reliability | 4 | 6 | 8 | 8
9 | Accuracy | 5 | 6 | 6 | 5
10 | Range | 4 | 8 | 7 | 6
| Total Marks | 53 | 60 | 63 | 59
Criterion | Block Diagram - 1 | Block Diagram -2 | Block Diagram -3 | Block Diagram -4 (User Centred Design)
Added features | • Only one powerful detector to detect sound | • A detection array instead of a single detector for sound detection | • A detection array instead of a single detector for sound detection | • A detection array instead of a single detector for sound detection
Removed features | • No Wi-Fi or Bluetooth connection can be enabled. | • No Wi-Fi connection can be enabled. | • No Bluetooth connection can be enabled. | • No Bluetooth connection can be enabled.

5. Selected Design for the Product; ii. Block diagram - Block diagram - 3; Detector; Array; Amplifier; Processor; Display; Wi-Fi connect; Power; Audio Input

i. Conceptual design - Design - 3 (Wall mount design)

### 6. Contribution from Each Group Member

- Group members
- Bandara D.M.D.V. | - | 200061N
- Bandara H.M.S.D. | - | 200064C
- Chandira R.M. | - | 200082E
- Hewavitharana M.I. | - | 200220D
- Marasinghe M.M.H.N.B. | - | 200381U
- Pramuditha A.A.H. | - | 200476P
- Samarasekara A.M.P.S. | - | 200558U
- Wijetunga W.L.N.K | - | 200733D

References

[1] R. Verganti, “Research Summary - Design Driven Innovation,” [Online]. Available: https://www.hbs.edu/faculty/Pages/item.aspx?research=7465. [Accessed 4 6 2023].
[2] Engineering Design Centre, Department of Engineering, University of Cambridge, “Inclusive Design Toolkit,” [Online]. Available: http://www.inclusivedesigntoolkit.com/GS_overview/overview.html. [Accessed 3 6 2023].
Index Number | Name | Contribution
200061N | Bandara D.M.D.V. | Criteria for both evaluation matrices, Block diagram - 2
200064C | Bandara H.M.S.D. | Criteria for both evaluation matrices, Block diagram - 1
200082E | Chandira R.M. | Criteria for both evaluation matrices, Conceptual design - 3
200220D | Hewavitharana M.I. | Criteria for both evaluation matrices, Conceptual design - 2
200381U | Marasinghe M.M.H.N.B. | Criteria for both evaluation matrices, Block diagram - 1
200476P | Pramuditha A.A.H. | Criteria for both evaluation matrices Conceptual design - 1
200558U | Samarasekara A.M.P.S. | Criteria for both evaluation matrices, Block diagram - 3

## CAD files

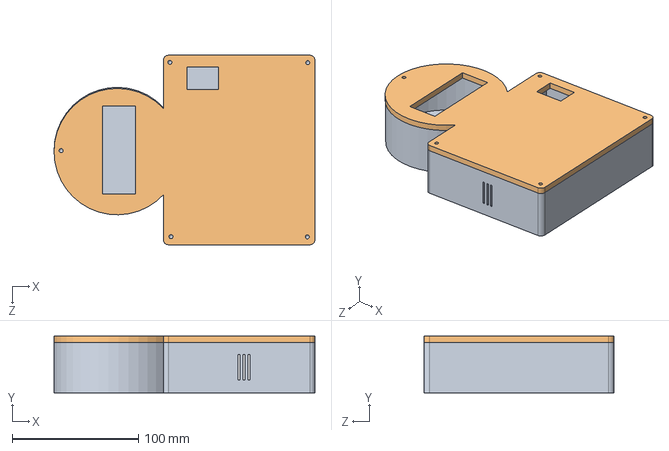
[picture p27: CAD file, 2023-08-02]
Enclosure design/Version 3/Enclosure.SLDASM
206.5 x 45.0 x 150.0 mm
New_Design
New_Design_Lid

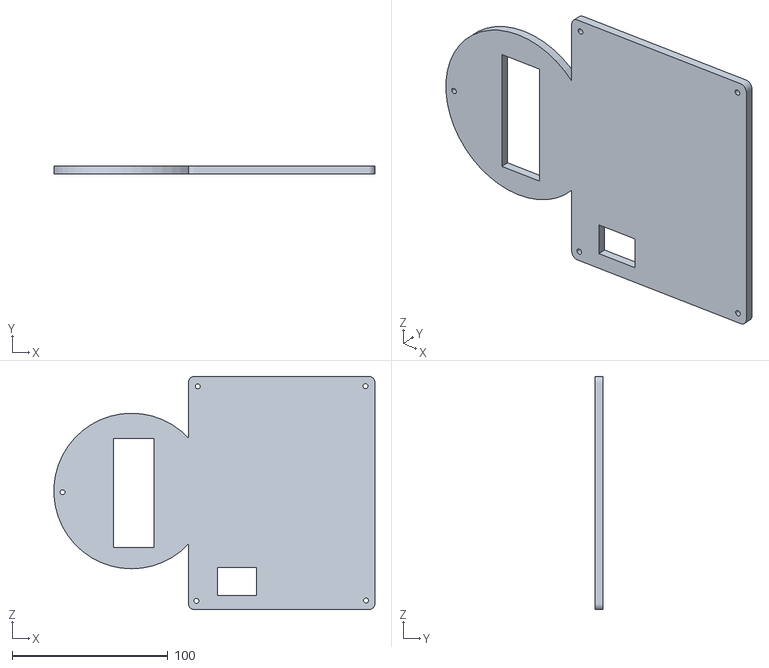
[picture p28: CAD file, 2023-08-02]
Enclosure design/Version 3/For 3D Printing/New_Design_Lid.STL
206.4 x 5.00 x 150.0

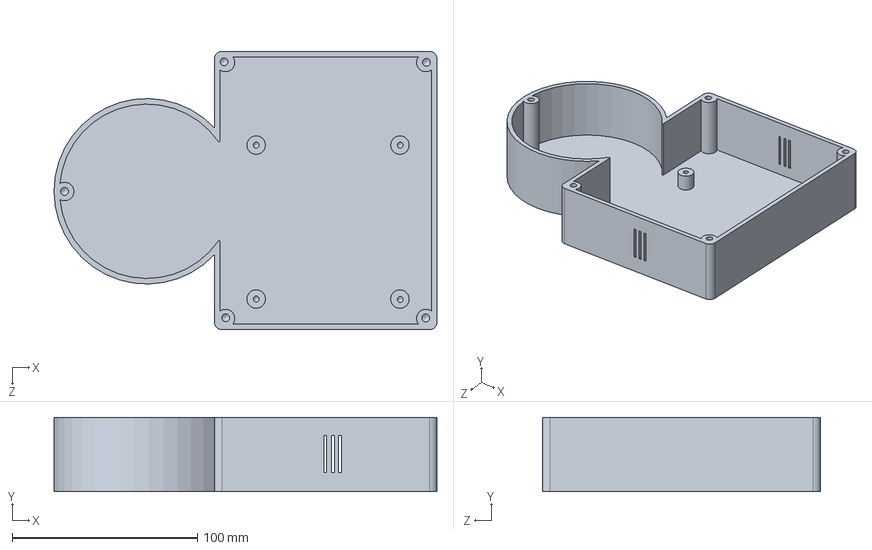
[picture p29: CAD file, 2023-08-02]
Enclosure design/Version 3/New_Design.SLDPRT
206.5 x 40.0 x 150.0 mm

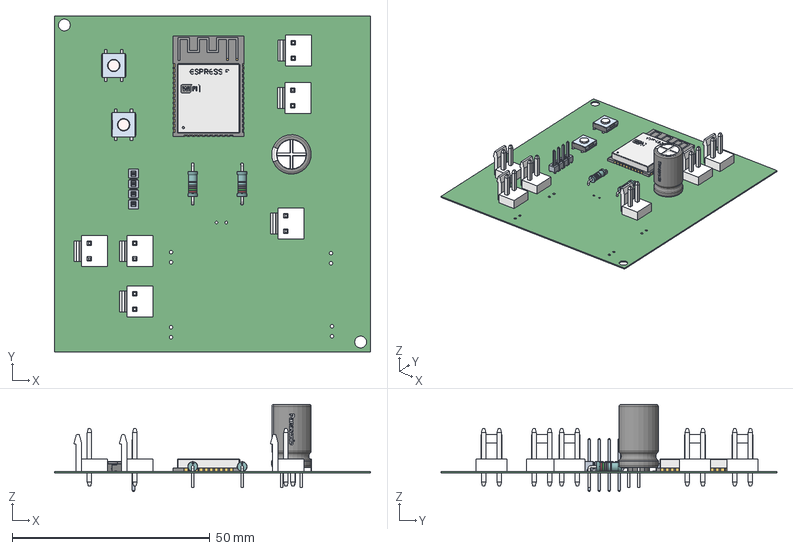
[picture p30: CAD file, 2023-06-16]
Schematics/Version_3/PCB_Updated.step
80.0 x 85.0 x 22.1 mm
User_Library-B2P-VH_B2P-body_white x 6
User_Library-B2P-VH_PinVH x 12
base x 2
top_cover x 2
Vishay x 2
pcb
pads
antenna
logo x 2
C2
marking
bottom
polarity_marking
top
terminal
TSW-104-08-X-S

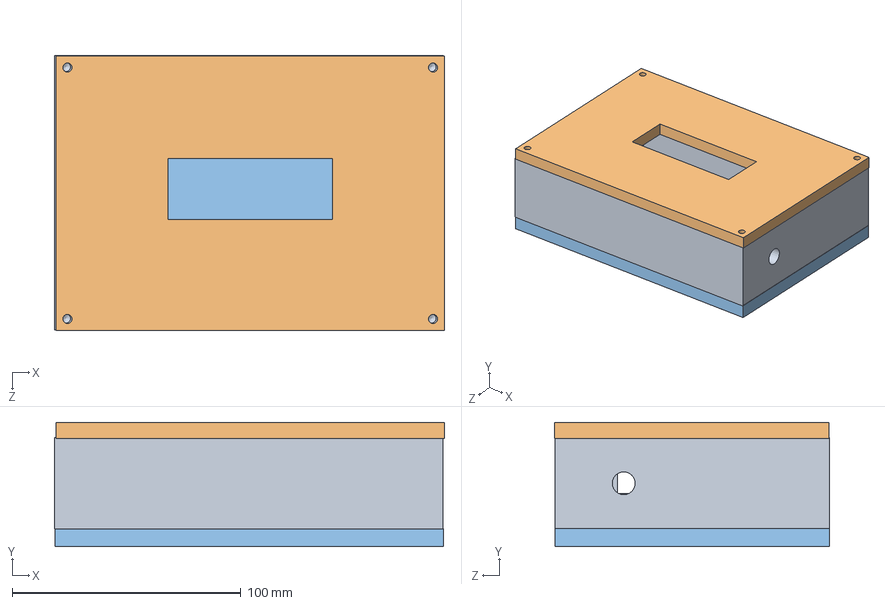
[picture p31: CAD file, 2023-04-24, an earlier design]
Enclosure design/Version 1/Enclosure_V1.SLDASM
170.7 x 54.5 x 120.2 mm
Lid
Base

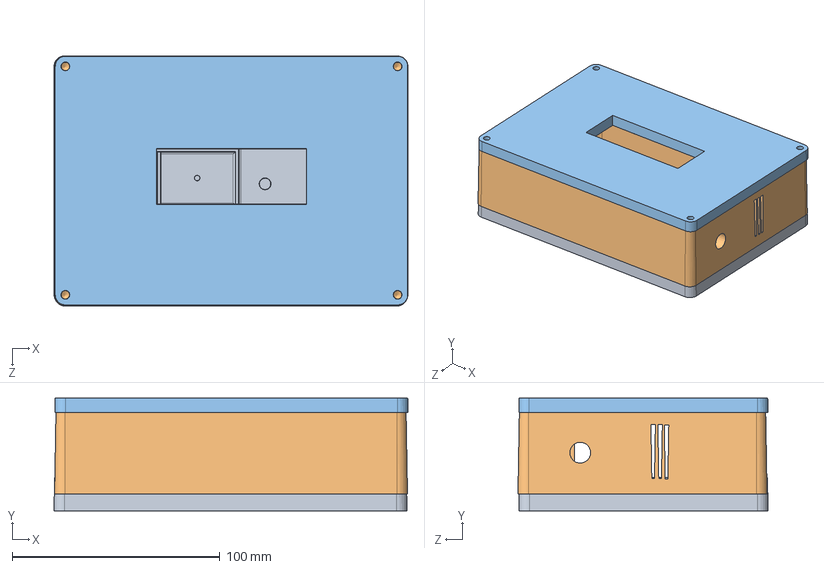
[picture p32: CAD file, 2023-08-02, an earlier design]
Enclosure design/Version 2/With draft/Design_with_draft.SLDASM
170.5 x 54.2 x 120.5 mm
Base_with_draft
Wall_with_draft
Lid_with_draft

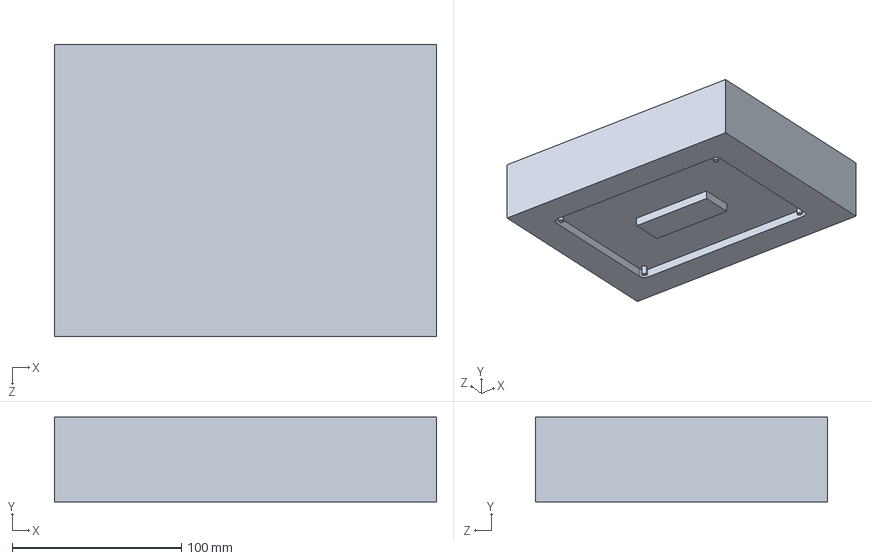
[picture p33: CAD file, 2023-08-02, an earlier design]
Enclosure design/Version 2/With draft/lid_cavity.SLDPRT
225.7 x 50.0 x 172.3 mm

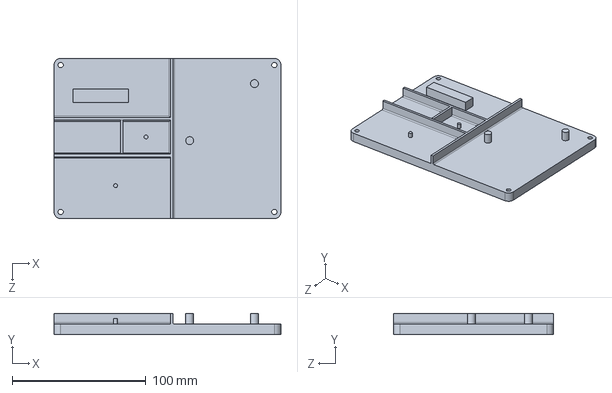
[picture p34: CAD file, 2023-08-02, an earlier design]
Enclosure design/Version 2/Without draft/Base.SLDPRT
170.0 x 16.0 x 120.0 mm

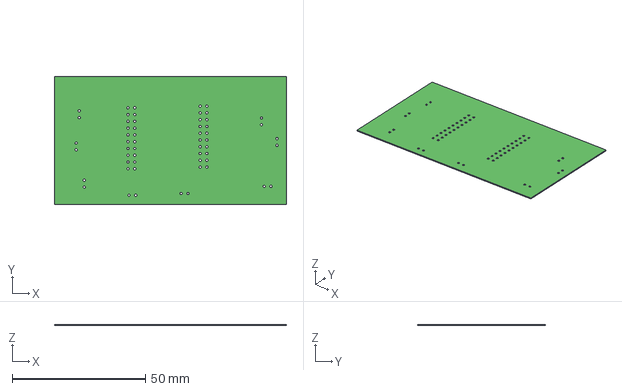
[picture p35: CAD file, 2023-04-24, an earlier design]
Schematics/Version_1/PCB1.step
87.0 x 48.1 x 0.411 mm

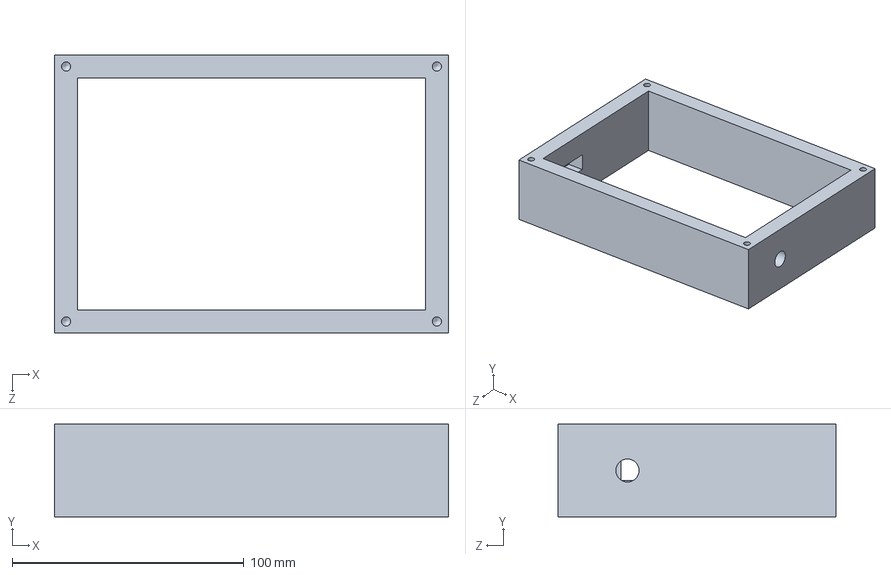
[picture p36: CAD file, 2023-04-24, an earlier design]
Enclosure design/Version 1/Part2.SLDPRT
170.0 x 40.0 x 120.0 mm

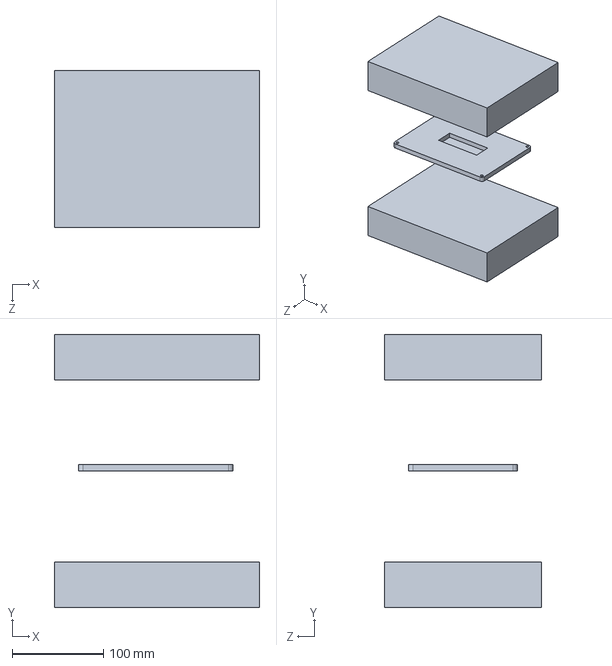
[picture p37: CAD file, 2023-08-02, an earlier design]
Enclosure design/Version 2/With draft/lid_mold.SLDPRT
225.7 x 300.0 x 172.3 mm

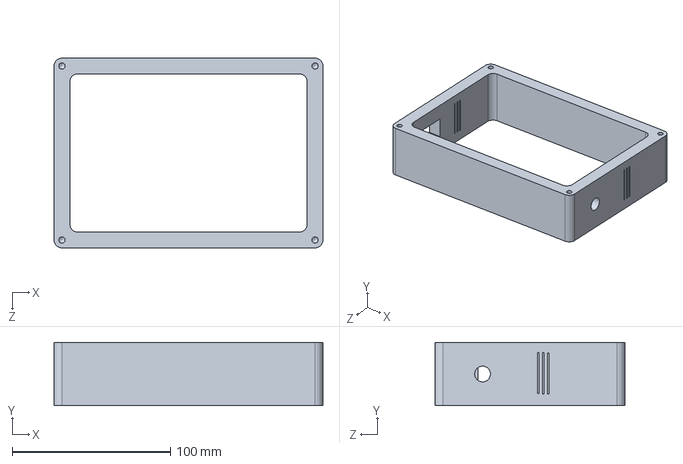
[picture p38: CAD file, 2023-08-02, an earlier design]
Enclosure design/Version 2/Without draft/Part2.SLDPRT
170.0 x 40.0 x 120.0 mm

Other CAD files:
Enclosure design/Version 3/With Draft/New_Design_Lid_With_Draft.SLDPRT
Enclosure design/Version 3/For 3D Printing/New_Design.STL
Enclosure design/Version 3/With Draft/New_Design_With_Dradt.SLDPRT
Enclosure design/Version 3/New_Design_Lid.SLDPRT
Enclosure design/Version 1/Enclosure_V1_STEP_File.STEP
Enclosure design/Version 1/Base.SLDPRT
Enclosure design/Version 1/Lid.SLDPRT
Enclosure design/Version 2/With draft/Base_with_draft.SLDPRT
Enclosure design/Version 2/With draft/Lid_with_draft.SLDPRT
Enclosure design/Version 2/With draft/Wall_with_draft.SLDPRT
Enclosure design/Version 2/With draft/lid_die.SLDPRT
Enclosure design/Version 2/Without draft/Enclosure_V1_STEP_File.STEP
Enclosure design/Version 2/Without draft/Lid.SLDPRT

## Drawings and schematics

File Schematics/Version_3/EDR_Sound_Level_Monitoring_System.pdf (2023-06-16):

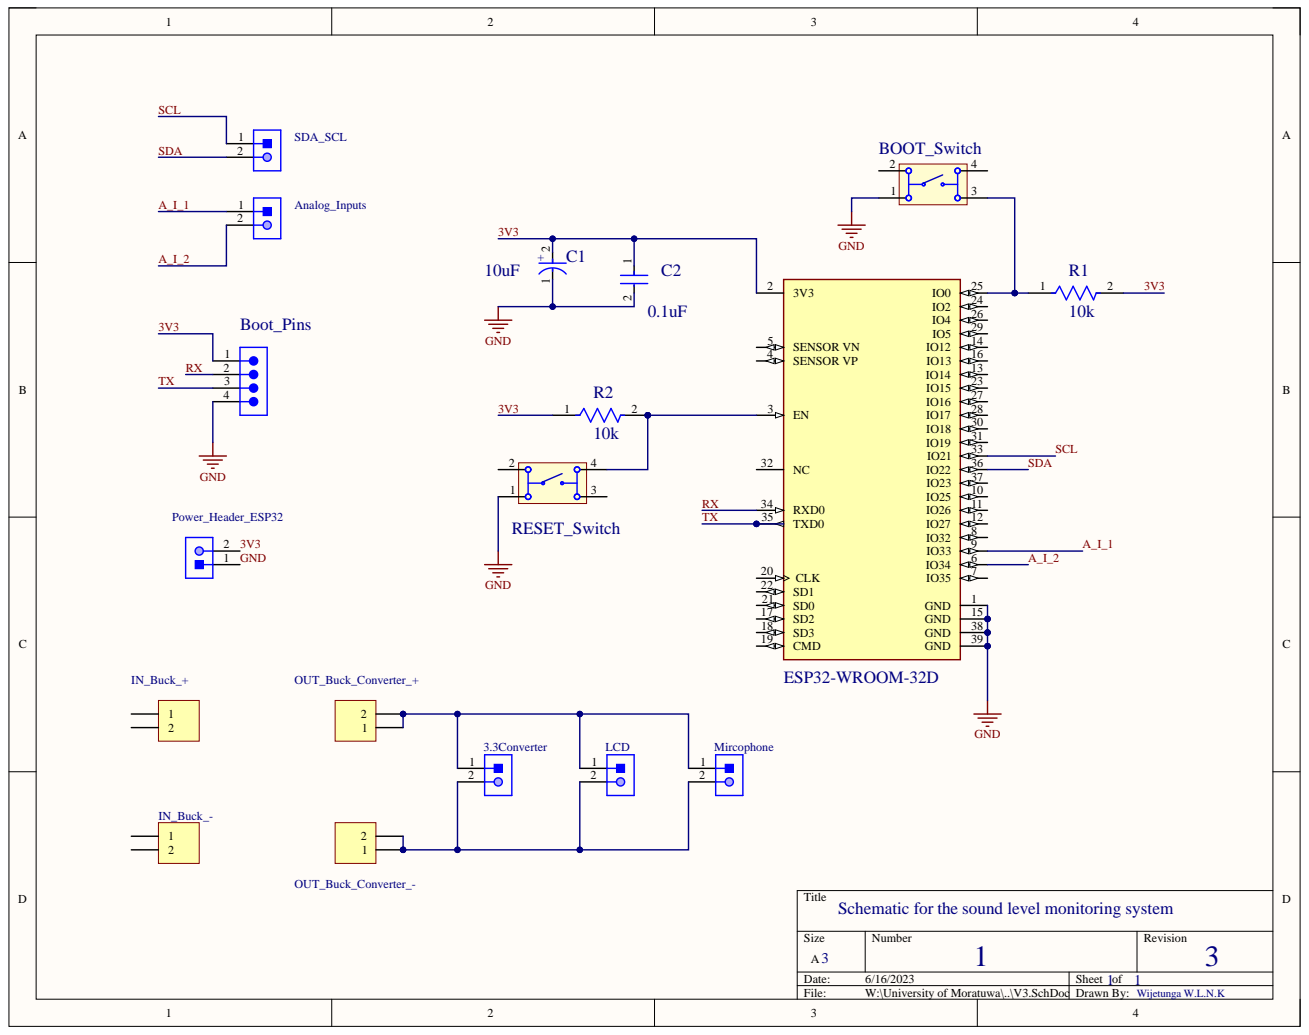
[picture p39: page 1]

Title
Schematic for the sound level monitoring system

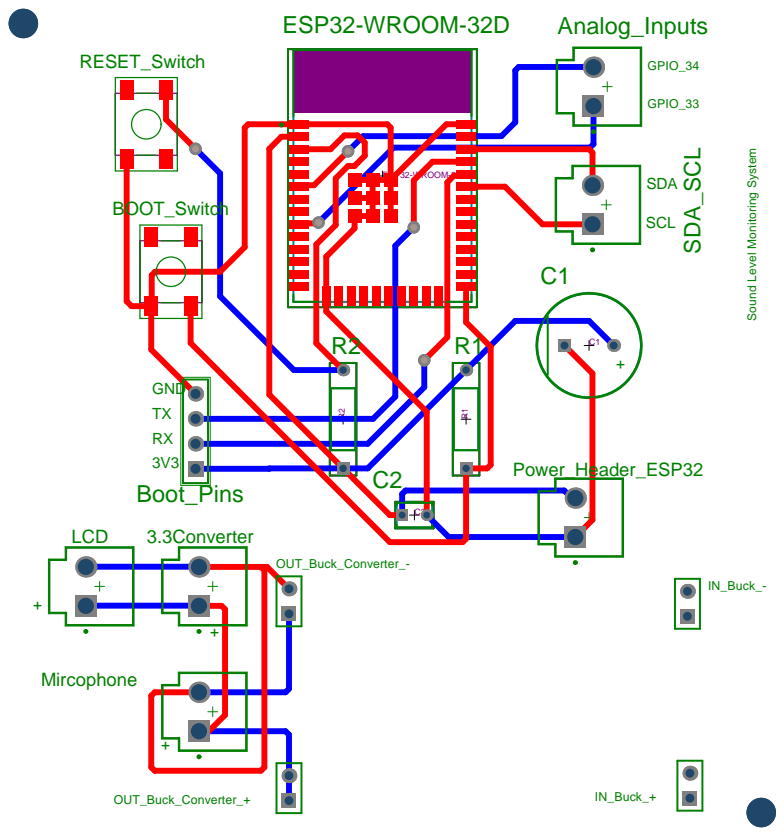
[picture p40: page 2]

Sound Level Monitoring System

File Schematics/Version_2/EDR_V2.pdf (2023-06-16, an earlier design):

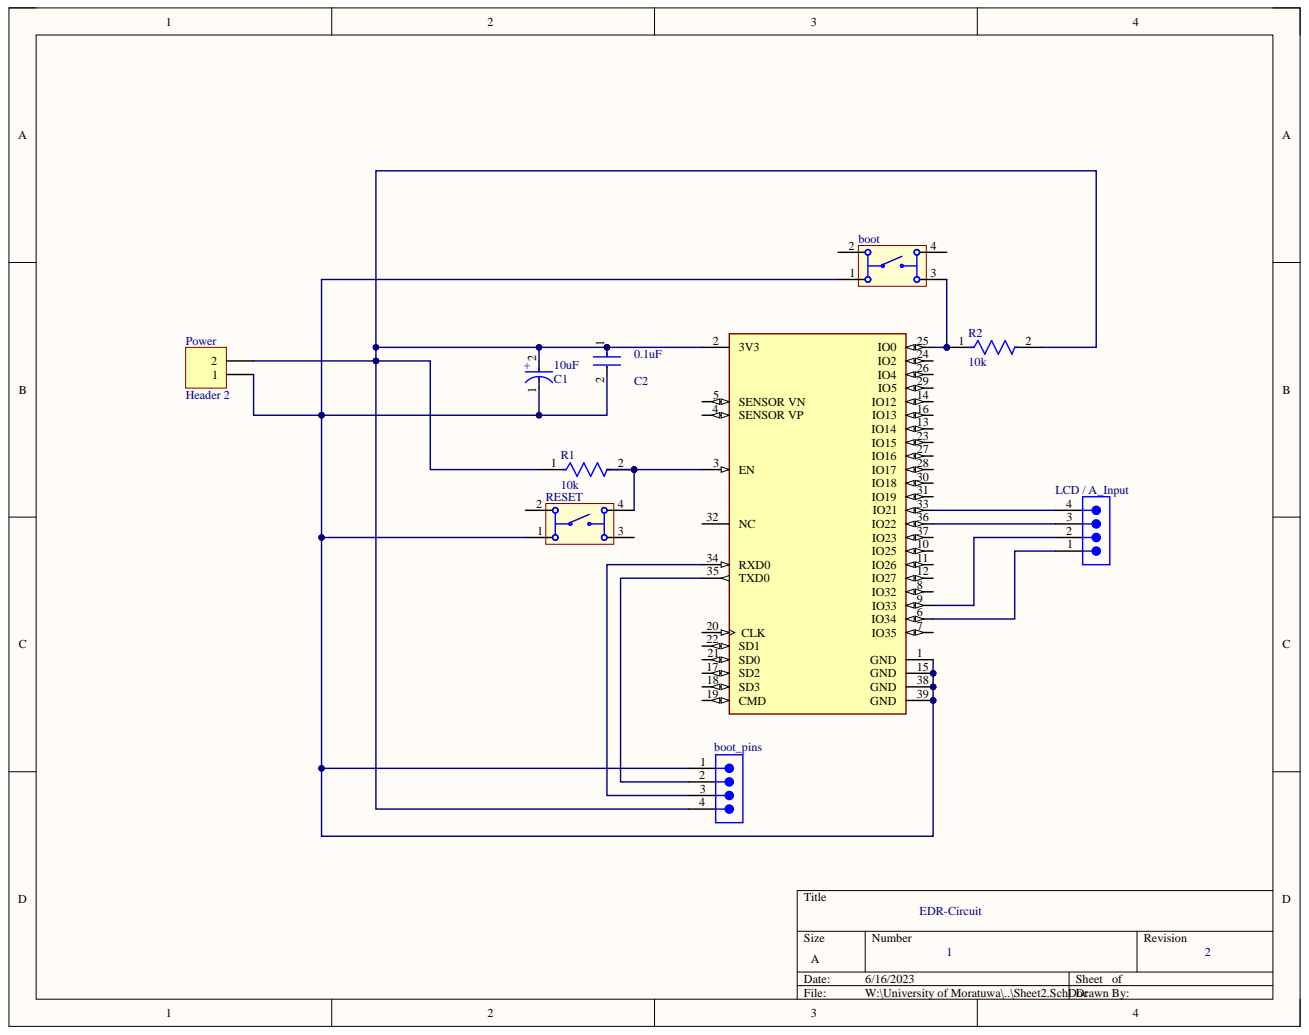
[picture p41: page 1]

NC 32
RXD0 34 | 2

TXD0 35

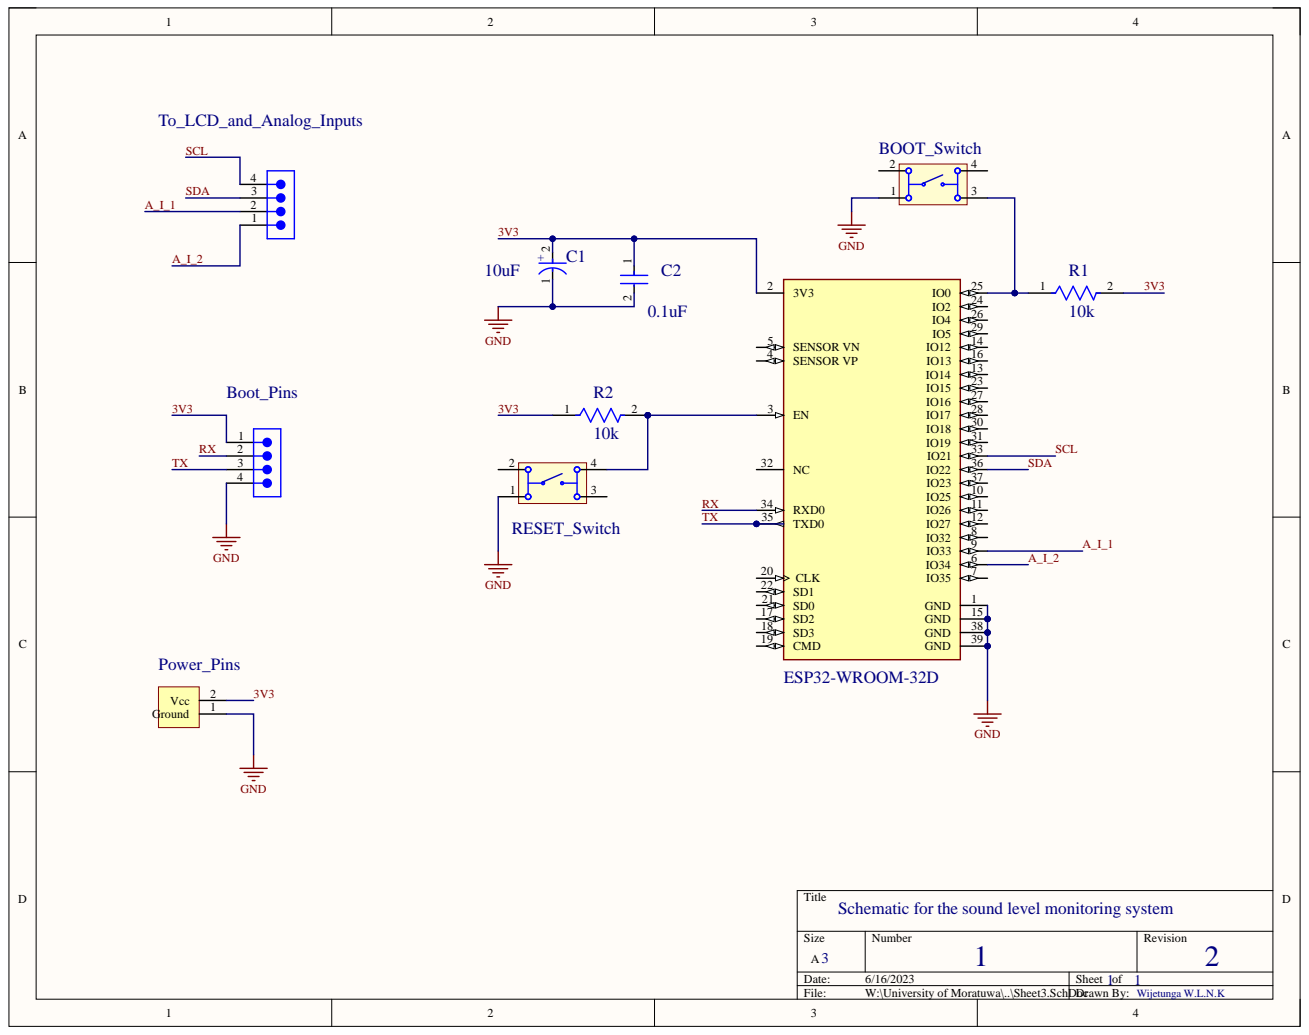
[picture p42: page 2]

Title
Schematic for the sound level monitoring system

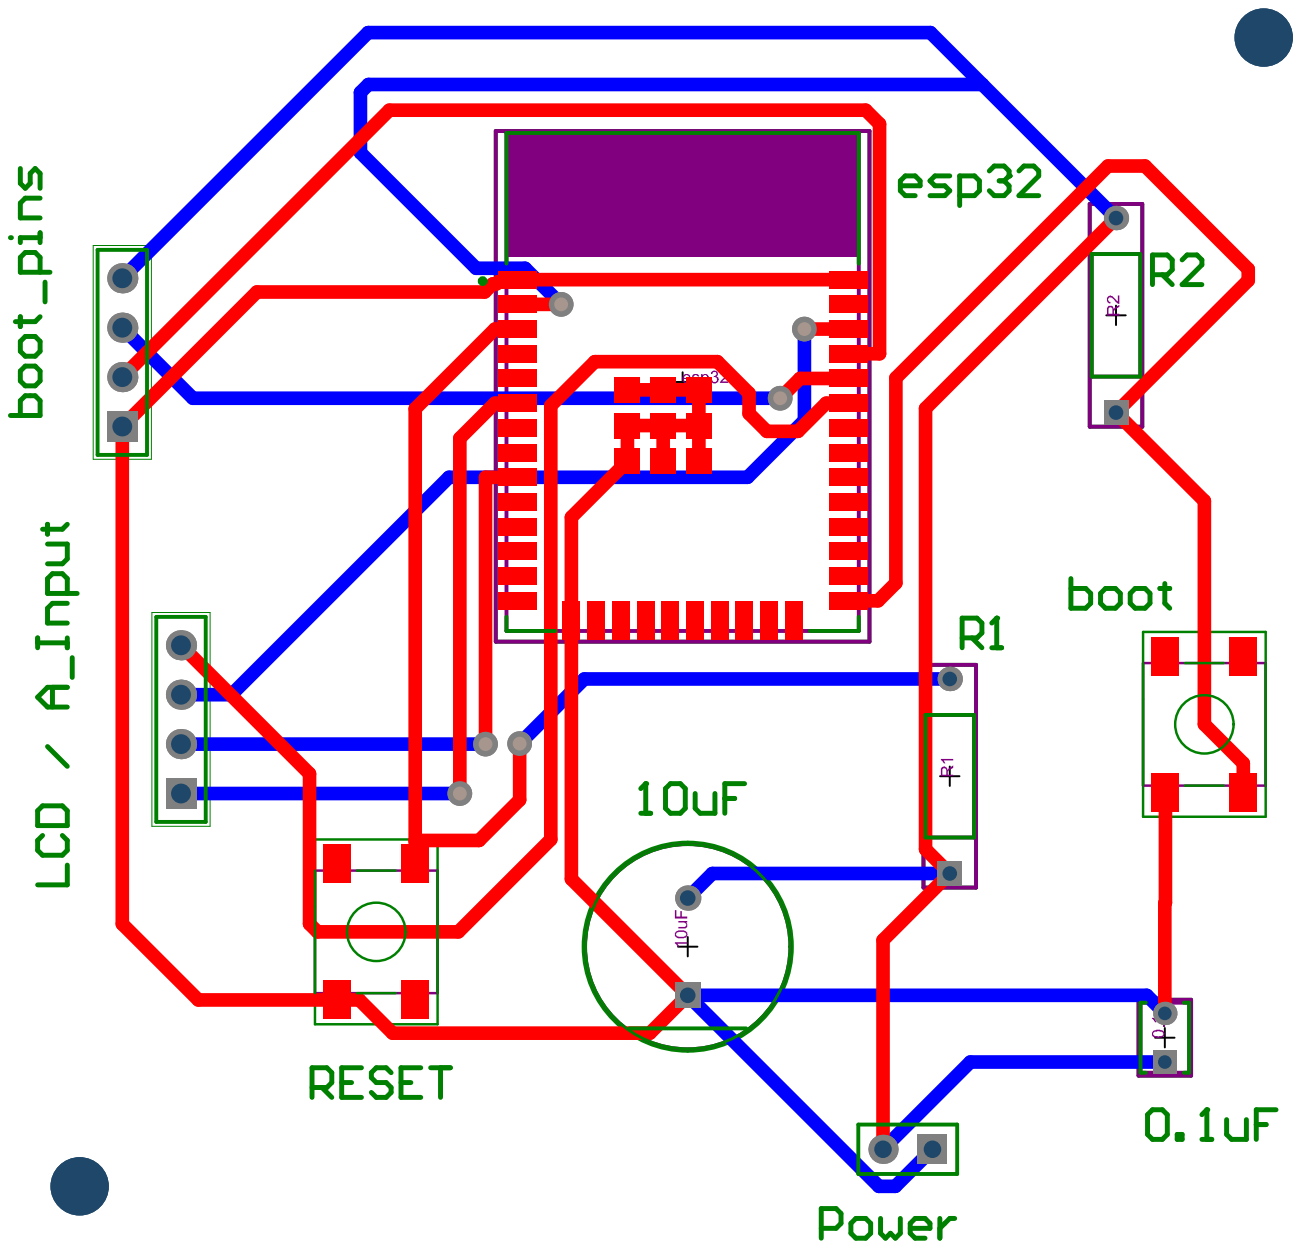
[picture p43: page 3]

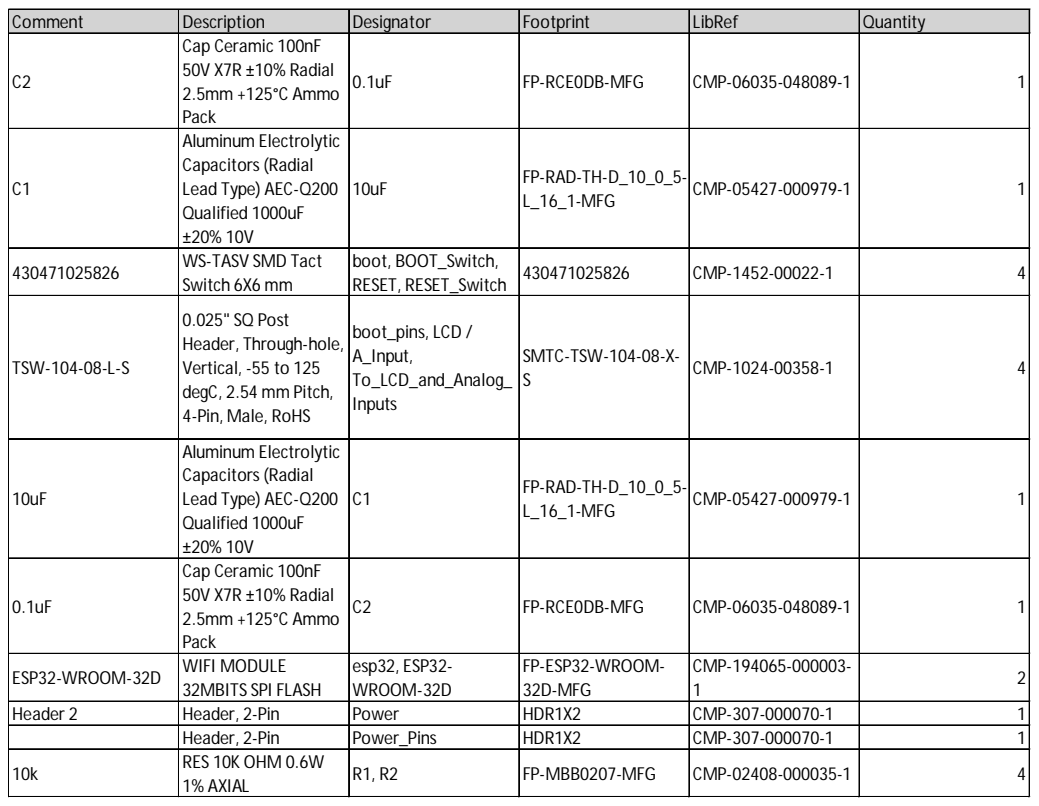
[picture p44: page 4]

Comment | Description | Designator | Footprint | LibRef | Quantity
C2 | Cap Ceramic 100nF 50V X7R ±10% Radial 2.5mm +125°C Ammo Pack | 0.1uF | FP-RCE0DB-MFG | CMP-06035-048089-1 | 1

C1 | Aluminum Electrolytic Capacitors (Radial Lead Type) AEC-Q200 Qualified 1000uF ±20% 10V | 10uF | FP-RAD-TH-D_10_0_5-L_16_1-MFG | CMP-05427-000979-1 | 1

430471025826 | WS-TASV SMD Tact Switch 6X6 mm | boot, BOOT_Switch, RESET, RESET_Switch | 430471025826 | CMP-1452-00022-1 | 4

TSW-104-08-L-S | 0.025" SQ Post Header, Through-hole, Vertical, -55 to 125 degC, 2.54 mm Pitch, 4-Pin, Male, RoHS | boot_pins, LCD / A_Input, To_LCD_and_Analog_ Inputs | SMTC-TSW-104-08-X-S | CMP-1024-00358-1 | 4

10uF | Aluminum Electrolytic Capacitors (Radial Lead Type) AEC-Q200 Qualified 1000uF ±20% 10V | C1 | FP-RAD-TH-D_10_0_5-L_16_1-MFG | CMP-05427-000979-1 | 1

0.1uF | Cap Ceramic 100nF 50V X7R ±10% Radial 2.5mm +125°C Ammo Pack | C2 | FP-RCE0DB-MFG | CMP-06035-048089-1 | 1

ESP32-WROOM-32D | WIFI MODULE 32MBITS SPI FLASH | esp32, ESP32-WROOM-32D | FP-ESP32-WROOM-32D-MFG | CMP-194065-000003-1 | 2

Header 2 | Header, 2-Pin | Power | HDR1X2 | CMP-307-000070-1 | 1

Header, 2-Pin | Power_Pins | HDR1X2 | CMP-307-000070-1 | 1

10k | RES 10K OHM 0.6W 1% AXIAL | R1, R2 | FP-MBB0207-MFG | CMP-02408-000035-1 | 4

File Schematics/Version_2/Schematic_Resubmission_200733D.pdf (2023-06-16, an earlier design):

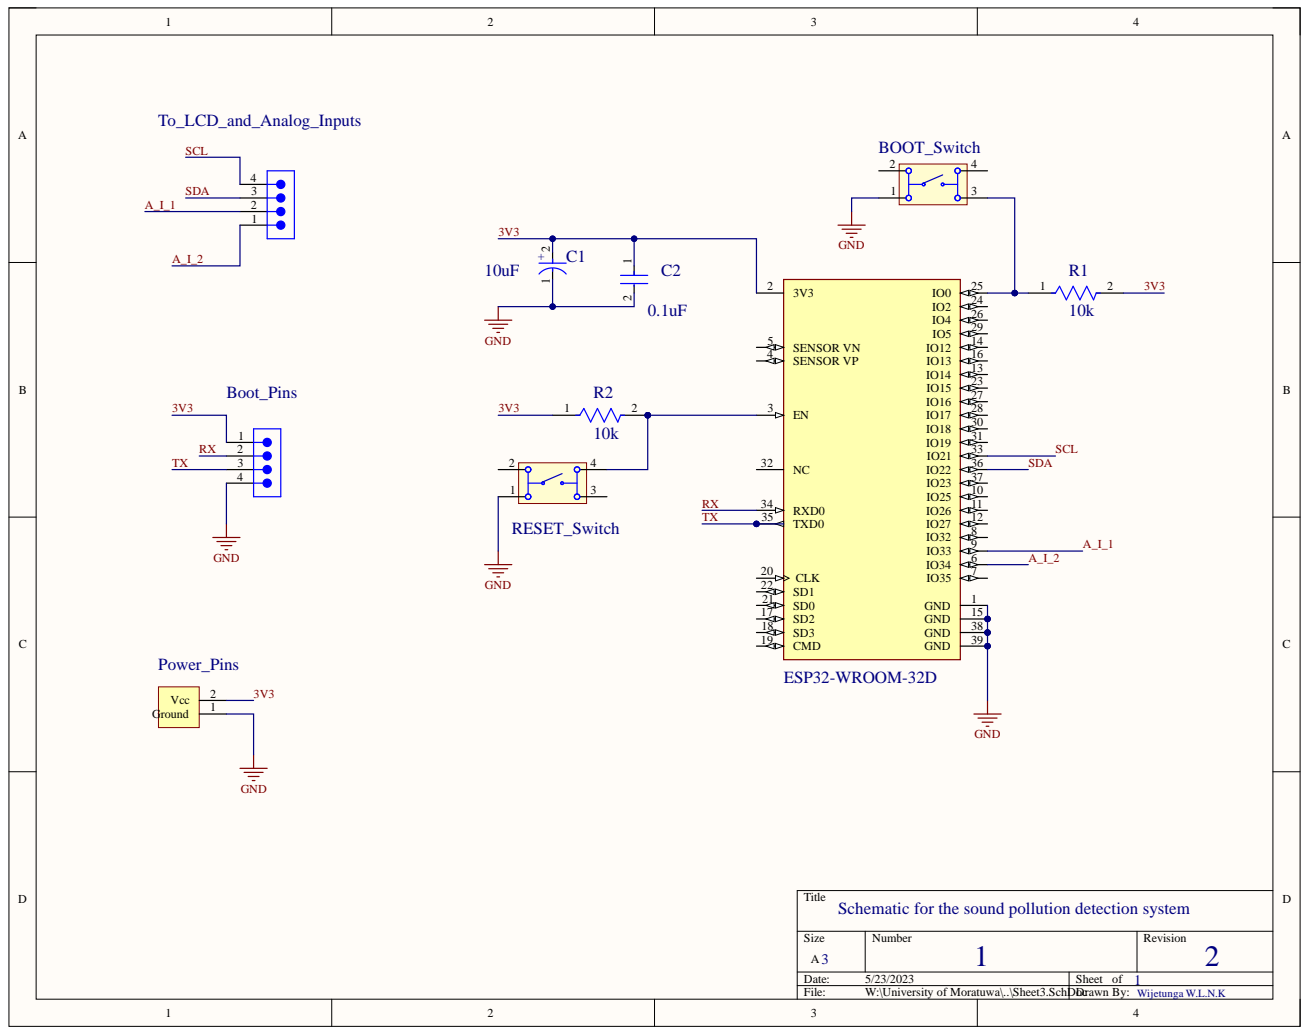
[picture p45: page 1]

Title
Schematic for the sound pollution detection system

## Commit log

2023-04-24 Enclosure design for the product
    [Base.SLDPRT, Enclosure_V1.SLDASM, Enclosure_V1_STEP_File.STEP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]
2023-06-16 Create Schematics
